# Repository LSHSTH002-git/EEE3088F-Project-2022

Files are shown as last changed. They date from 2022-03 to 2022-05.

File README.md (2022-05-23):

# EEE3088F_2022: GROUP 15 LIGHT SENSOR HAT PROJECT

In this guide we will learn to use the LIGHT SENSOR HAT that is used to detect environmental changes and then set off an alarm to alert the onwner about the changes.

This Sensor is primarily designed for farmers that want to monitor their live stock and prevent thieves from stealing them.



# What you will need
1. You will need an STM32f0discovery board

2. Li-Ion battery

3. jumpers

4.  Laptop

5. Micro usb type B male connector

6. STM32CubeIDE

7. Mini USB type A cable

8. The HAT code

9. The HAT pcb Board

# Setting up the System

Insert the Li-ion battery to the battery holder
connect the STM32f0discovery board to your laptop using the Mini USB type A cable
connect the light sensor HAT to your Laptop using Micro usb type B male connector and you should see two LED's light up
run the HAT code on your pc using STM32CubeIDE 
if you cover up the Light sensor HAT, the Blue LED on the STM32f0discovery board should blink

if you stop covering the Light sensor HAT the blue LED should stop blinking.


# License
[Creative Commons Attribution 4.0 International license](https://choosealicense.com/licenses/cc-by-4.0/)

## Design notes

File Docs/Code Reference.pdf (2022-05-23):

Code Reference

STM32F0 LSPCB1x

### Code Description of the STM32F0 LSPCB1x PCB

Introduction

The STM32F0 LSPCB1x pcb integrates with the stm32 microcontroller to perfom the necessary operations using the data retrieved from the sensor in the PCB. In this code reference document the programming language c is used, however the PCB isn’t only limited to c, c++ can also be used. Following are the fucntions used in the program, with details on how each plays into the whole fundumental program.

System Clock Configuration:

void SystemClock_Config(void);

This function initializes the Reset and Clock Control(RCC) registers of the STM32 microcontroller. The function initializes the RCC oscillators in accordance with the user specified parameters. Shown below is code snippet, showing the latter.

void SystemClock_Config(void)

{…

RCC_OscInitTypeDef RCC_OscInitStruct = {0};

RCC_OscInitStruct.OscillatorType = RCC_OSCILLATORTYPE_HSI;

…}

The function also goes on to handle initialization of the CPU, AHB and APB buses’ clocks, to which a user may modify to work best for their application.

GPIO Pins Configuration:

static void MX_GPIO_Init(void);

This function initialized the STM32 GPIO pins, to which the user may add on other pins should there be a need of some GPIO pins. The code snippet below shows how to initialize and use a GPIO pin by toggling the STM32 blue LED, but before that RCC clocks have to be enabled for the appropriate GPIOs.

static void MX_GPIO_Init(void)

{…

//enabling a clock

__HAL_RCC_GPIOC_CLK_ENABLE();

HAL_GPIO_WritePin(GPIOC, GPIO_PIN_8, GPIO_PIN_RESET

…}

Code Reference

USART2 Initialization:

static void MX_USART2_UART_Init(void);

This function handles the initialization of the USB to serial converter. A FT232RL 3.3V / 5.5V FTDI USB is integrated with the PCB for this purpose. The function sets multiple parameters for the communication link, from Baud rate to Word Length and other parameters involved. Below is code snippet showing how some of the parameters are set in the function:

static void MX_USART2_UART_Init(void)

{…

huart2.Instance = USART2;

huart2.Init.BaudRate = 9600;

huart2.Init.WordLength = UART_WORDLENGTH_8B;

…}

I2C1 Initialization:

static void MX_I2C1_Init(void);

The PCB uses the I2C communication protocol, where data is transmitted bit by bit along the SDA wire on a shared clock signal. This function initializes the I2C protocol by setting the appropriate parameters demonstrated below.

static void MX_I2C1_Init(void)

{…

hi2c1.Instance = I2C1;

hi2c1.Init.Timing = 0x2000090E;

hi2c1.Init.OwnAddress1 = 0;

…}

Code Reference
Error Detection and Handler

void Error_Handler(void);

This function is the failsafe of the program for the anticipated errors that might occur, it is the function that executes when an error is detected in the program.

void Error_Handler(void)

{…

//user may add code here.

__disable_irq();

…}

This function can be called under multiple functions if an error is detected, below is a demonstration where the function is called to perform the user desired instruction when an error is detected under USART2 initialization

static void MX_USART2_UART_Init(void)

{…

if (HAL_UART_Init(&huart2) != HAL_OK)

{

Error_Handler();

}

…}

The Main Function

int main(void);

The main function in the main.c file is the execution function of all the used functions and files for the program. From the initializations of the other functions, to the data processing where data is retrieved from the sensor, written to the EEPROM and sent to the program via the USART serial com.

All the initializing functions are called in main before any other processing is done so that all the necessary GPIOs and clocks are set. The user may extend under the main function to add other functions they may wish to add. The main function is created as follows:

int main(void)

{

//All the initializing functions are called

SystemClock_Config();

MX_GPIO_Init(void);

Code Reference

Data processing between the computer, EEPROM and the PCB sensors.

//And the user may add their own code below.

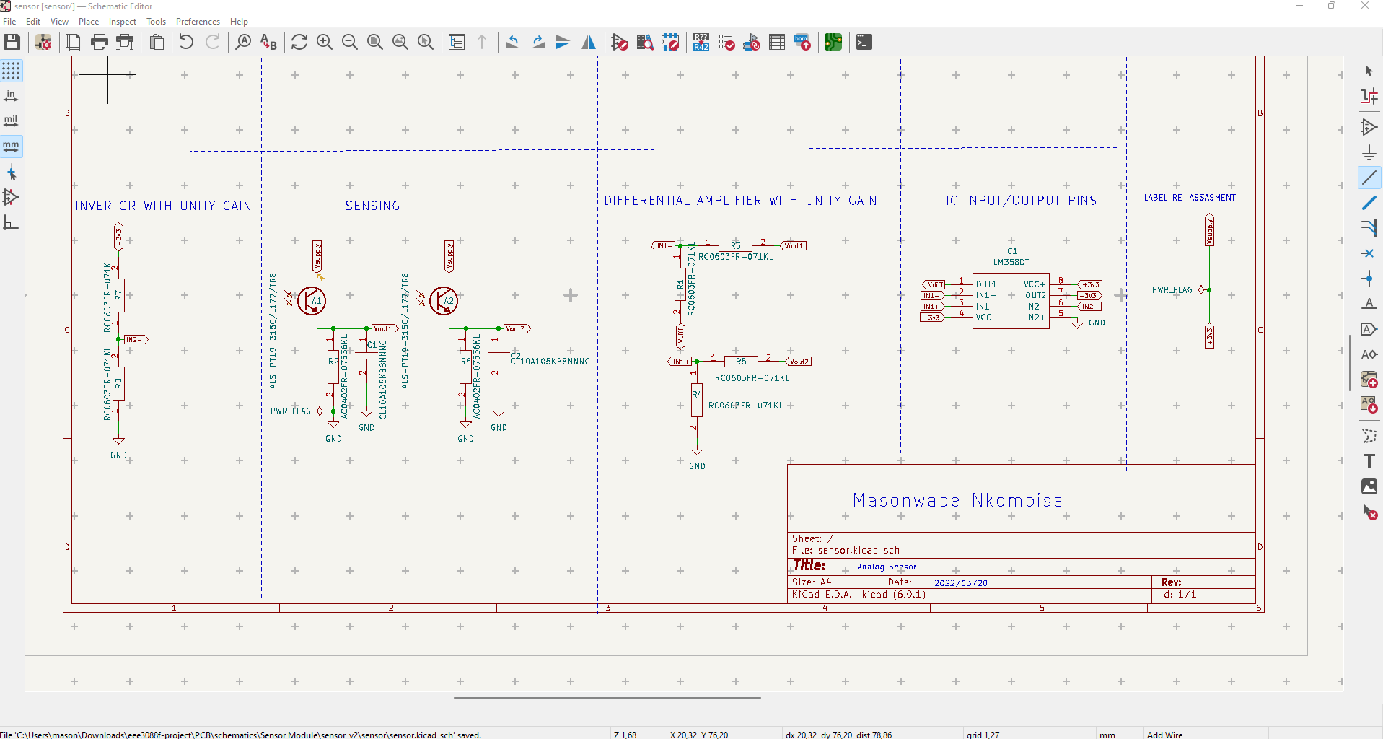
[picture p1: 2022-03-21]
PCB/schematics/Sensor Module/sensor/Sensor Sub System.png

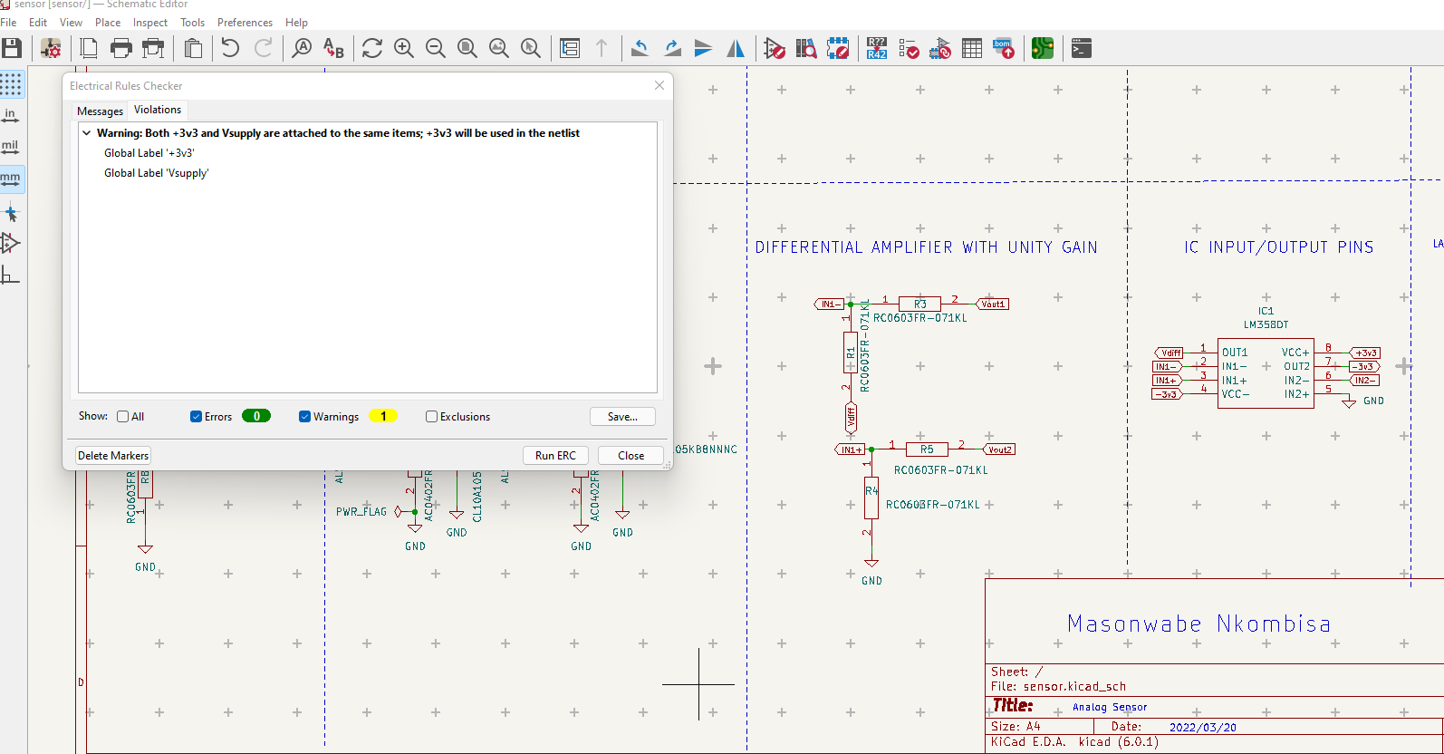
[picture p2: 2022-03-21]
PCB/schematics/Sensor Module/sensor/Sensor ERC.png

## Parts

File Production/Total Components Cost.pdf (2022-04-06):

# Total Components Cost

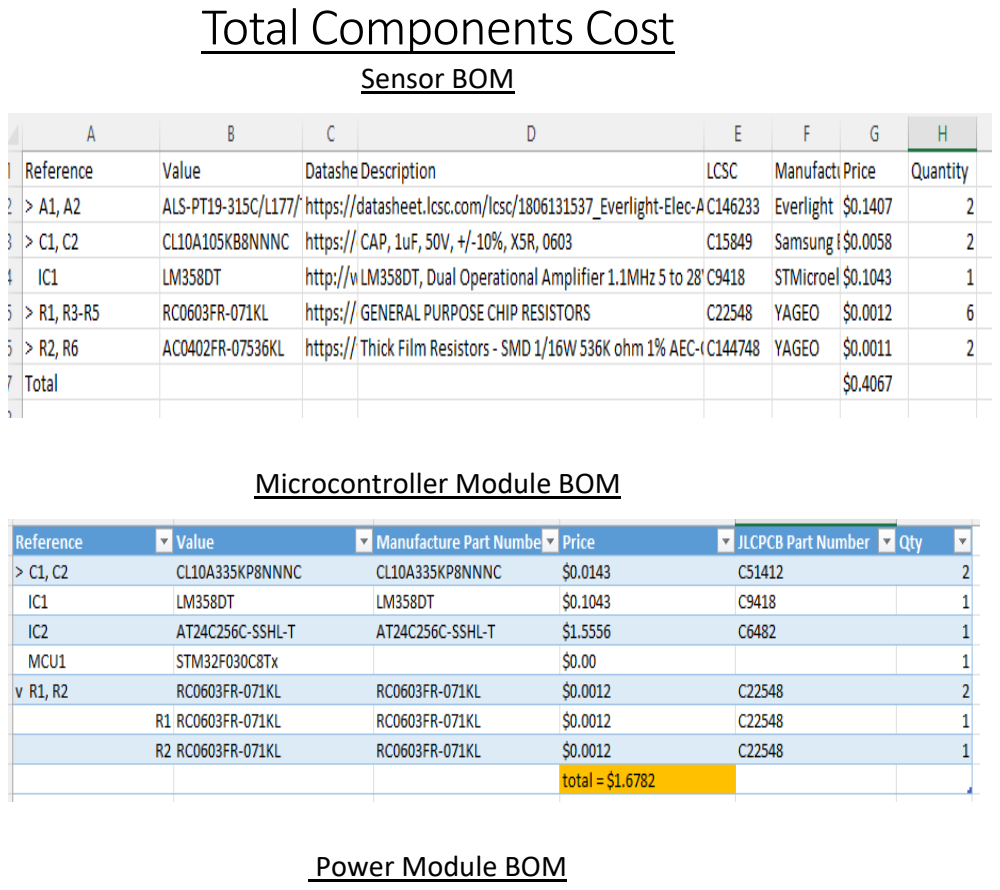
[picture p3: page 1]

Sensor BOM

Microcontroller Module BOM

Power Module BOM

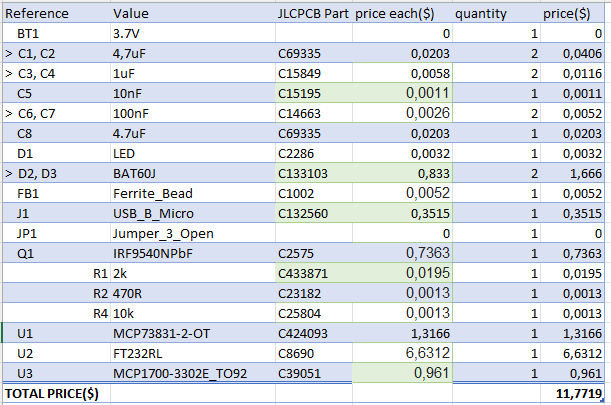
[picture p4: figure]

Total Cost of Components: $13.8568

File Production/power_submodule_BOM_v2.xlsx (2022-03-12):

Reference | Quantity | Value | JLCPCB Part | price
BT1 charger | 1 |  | CN3083 | 0.0007
BT1 | 1 | 3.7V |  | 0
C1 C2 | 2 | 4,7uF | C8032 | 0,004
C3 C4 | 2 | 1uF | C15849 | 0.0058
C5 | 1 | 10nF | C1710 | 0.0064
C6 C7 | 2 | 100nF | C14663 | 0.0026
C8 | 1 | 4.7uF | C1538 | 0.0011
D1 | 1 | LED | C264544 | 0,1584
D2 | 1 | BAT60J | C2476 | 0.108
D3 | 1 | BAT60J | C2476 | 0.108
J1 | 1 | USB_B_Micro | C132563 | 0,2511
Q1 | 1 | IRF9540NPbF | C2575 | 0.7363
R1 | 1 | 2k | C25731 | 0.0073
R2 | 1 | 470R | C425292 | 0.0059
R3 | 1 | 220R | C433520 | 0,008
R4 | 1 | 10k | C29718 | 0.0071
U1 | 1 | MCP73831-2-OT | C424093 | 1,5435
U2 | 1 | FT232RL | C8690 | 6.6312
U3 | 1 | MCP1700-3302E_TO92 | C39051 | 0.961

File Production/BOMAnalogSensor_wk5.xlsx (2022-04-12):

Reference | Value | Datasheet | Description | LCSC | Manufacture | Price | Quantity
> A1, A2 | ALS-PT19-315C/L177/TR8 | https://datasheet.lcsc.com/lcsc/1806131537_Everlight-Elec-ALS-PT19-315C-L177-TR8_C146233.pdf |  | C146233 | Everlight | $0.1407 | 2
> C1, C2 | CL10A105KB8NNNC | https://datasheet.datasheetarchive.com/originals/distributors/Datasheets-DGA10/2411562.pdf | CAP, 1uF, 50V, +/-10%, X5R, 0603 | C15849 | Samsung Electro-Mechanics | $0.0058 | 2
IC1 | LM358DT | http://www.st.com/st-web-ui/static/active/en/resource/technical/document/datasheet/CD00000464.pdf | LM358DT, Dual Operational Amplifier 1.1MHz 5 to 28V, 8-Pin SO | C9418 | STMicroelectronics | $0.1043 | 1
> R1, R3-R5 | RC0603FR-071KL | https://datasheet.datasheetarchive.com/originals/distributors/Datasheets_SAMA/902f9e387b938f871d31120f5fc1d65e.pdf | GENERAL PURPOSE CHIP RESISTORS | C22548 | YAGEO | $0.0012 | 6
> R2, R6 | AC0402FR-07536KL | https://www.yageo.com/upload/media/product/productsearch/datasheet/rchip/PYu-AC_51_RoHS_L_8.pdf | Thick Film Resistors - SMD 1/16W 536K ohm 1% AEC-Q200 | C144748 | YAGEO | $0.0011 | 2
Total |  |  |  |  |  | $0.4067

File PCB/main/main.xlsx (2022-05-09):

Comment | Designator | Footprint | LCSC
ALS-PT19-315C/L177/TR8 | A1,A2 | SamacSys_Parts:XDCR_ALS-PT19-315C_L177_TR8 | C146233
10nF | C1 | SamacSys_Parts:CAPC1608X90N | C15195
CL10A335KP8NNNC | C11,C12 | SamacSys_Parts:CAPC1608X90N | C51412
CC0603KRX7R9BB104 | C13 | SamacSys_Parts:CAPC1608X90N | C14663
CL31A106KBHNNNE | C2,C6,C7,C8 | SamacSys_Parts:CAPC3216X180N | C13585
100nF | C3,C4 | SamacSys_Parts:CAPC1608X90N | C14663
CL21C101JBANNNC | C5 | SamacSys_Parts:CAPC2012X75N | C1790
CL10A105KB8NNNC | C9,C10 | SamacSys_Parts:CAPC1608X90N | C15849
SS14 | D1,D2 | SamacSys_Parts:DIOM5227X270N | C2480
LM358DT | IC1,IC2 | SamacSys_Parts:SOIC127P600X175-8N | C9481
AT24C256C-SSHL-T | IC3 | SamacSys_Parts:SOIC127P600X175-8N | C6482
TP4056-42-ESOP8 | IC4 | SamacSys_Parts:SOIC127P600X175-9N | C16581
Conn_01x33_Female | J1,J4 | Connector_PinHeader_2.54mm:PinHeader_1x33_P2.54mm_Vertical
ICH-340-CTT | J11 | SamacSys_Parts:DIPS762W74P254L5080H338Q40N | C84681
Conn_01x33_Female | J2,J3 | Connector_PinSocket_2.54mm:PinSocket_1x33_P2.54mm_Vertical
47346-0001 | J5 | SamacSys_Parts:47346-0001 | C132560
PZ254V-11-02P | J6,J7,J9,J10 | SamacSys_Parts:HDRV2W64P0X254_1X2_508X250X873P | C492401
MTP125-1103S1 | J8,J12,J13,J14,J15 | SamacSys_Parts:HDRV3W64P0X254_1X3_762X250X885P | C358685
19-217_GHC-YR1S2_3T | LED1,LED2 | SamacSys_Parts:LEDC1608X50N | C72043
AO3401A | Q1 | SamacSys_Parts:SOT95P280X125-3N | C15127
0603WAF1201T5E | R 1 | SamacSys_Parts:RESC1608X55N | C22765
RC0603FR-071KL | R2,R4,R5,R8,R9,R10,R11,R12,R13,R14 | SamacSys_Parts:RESC1608X55N | C22548
10k | R 3 | SamacSys_Parts:RESC1608X55N | C25804
AC0402FR-07536KL | R6,R7 | SamacSys_Parts:RESC1005X37N | C144748
HT75xx-1-SOT89 | U1 | Package_TO_SOT_SMD:SOT-89-3 | C14289

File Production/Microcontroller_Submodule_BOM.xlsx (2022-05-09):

Reference | Value | Manufacture Part Number | Price | JLCPCB Part Number | Qty
> C1, C2 | CL10A335KP8NNNC | CL10A335KP8NNNC | $0.0143 | C51412 | 2
IC1 | LM358DT | LM358DT | $0.1043 | C9418 | 1
IC2 | AT24C256C-SSHL-T | AT24C256C-SSHL-T | $1.5556 | C6482 | 1
MCU1 | STM32F030C8Tx |  | $0.00 |  | 1
v R1, R2 | RC0603FR-071KL | RC0603FR-071KL | $0.0012 | C22548 | 2
R 1 | RC0603FR-071KL | RC0603FR-071KL | $0.0012 | C22548 | 1
R 2 | RC0603FR-071KL | RC0603FR-071KL | $0.0012 | C22548 | 1
 |  |  | total = $1.6782

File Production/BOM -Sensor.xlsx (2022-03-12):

Reference | Quantity | Value | Footprint | Datasheet | Populate | Price | Alt_LCSC | LCSC
C1 C2 | 2 | 1uF |  | https://datasheet.lcsc.com/lcsc/1810271109_Samsung-Electro-Mechanics-CL31B105KBHNNNE_C1848.pdf |  | 0.026$/unit |  | C1848
R1 R2 R3 R4 R5 R6 | 6 | 1k |  | https://datasheet.lcsc.com/lcsc/1811141734_FH-Guangdong-Fenghua-Advanced-Tech-RC-02W1001FT_C226166.pdf |  | 0.001$/unit |  | C226166
U1 U2 | 2 | LTR-303ALS-01 | OptoDevice:Lite-On_LTR-303ALS-01 | http://optoelectronics.liteon.com/upload/download/DS86-2013-0004/LTR-303ALS-01_DS_V1.pdf |  | 0.384$/unit |  | C364577
U3 | 1 | 4011 |  | https://datasheet.lcsc.com/lcsc/1809050910_Texas-Instruments-CD4011BM96_C48466.pdf |  |  |  | C48466

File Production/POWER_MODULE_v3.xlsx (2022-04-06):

Column1 | Column2 | Column3 | Column4 | Column5 | Column6
Reference | Value | JLCPCB Part | price each($) | quantity | price($)
BT1 | 3.7V |  | 0 | 1 | 0
> C1, C2 | 4,7uF | C69335 | 0.0203 | 2 | 0.0406
> C3, C4 | 1uF | C15849 | 0.0058 | 2 | 0.0116
C5 | 10nF | C15195 | 0.0011 | 1 | 0.0011
> C6, C7 | 100nF | C14663 | 0.0026 | 2 | 0.0052
C8 | 4.7uF | C69335 | 0.0203 | 1 | 0.0203
D1 | LED | C2286 | 0.0032 | 1 | 0.0032
> D2, D3 | BAT60J | C133103 | 0.833 | 2 | 1.666
FB1 | Ferrite_Bead | C1002 | 0.0052 | 1 | 0.0052
J1 | USB_B_Micro | C132560 | 0.3515 | 1 | 0.3515
JP1 | Jumper_3_Open |  | 0 | 1 | 0
Q1 | IRF9540NPbF | C2575 | 0.7363 | 1 | 0.7363
R 1 | 2k | C433871 | 0.0195 | 1 | 0.0195
R 2 | 470R | C23182 | 0.0013 | 1 | 0.0013
R 4 | 10k | C25804 | 0.0013 | 1 | 0.0013
U1 | MCP73831-2-OT | C424093 | 1.3166 | 1 | 1.3166
U2 | FT232RL | C8690 | 6.6312 | 1 | 6.6312
U3 | MCP1700-3302E_TO92 | C39051 | 0.961 | 1 | 0.961
TOTAL PRICE($) |  |  |  |  | 11.7719

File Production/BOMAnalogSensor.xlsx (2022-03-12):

Reference | Quantity | Value | Footprint | Datasheet | LCSC | Price
C1 | 1 | 1uF |  | https://datasheet.lcsc.com/lcsc/1810271109_Samsung-Electro-Mechanics-CL31B105KBHNNNE_C1848.pdf | C1848 | 0.026$/unit
R1 R2 R3 | 3 | 1k |  | https://datasheet.lcsc.com/lcsc/1811141734_FH-Guangdong-Fenghua-Advanced-Tech-RC-02W1001FT_C226166.pdf | C226166 | 0.001$/unit
U1 | 1 | LTR-303ALS-01 | OptoDevice:Lite-On_LTR-303ALS-01 | http://optoelectronics.liteon.com/upload/download/DS86-2013-0004/LTR-303ALS-01_DS_V1.pdf | C364577 | 0.384$/unit

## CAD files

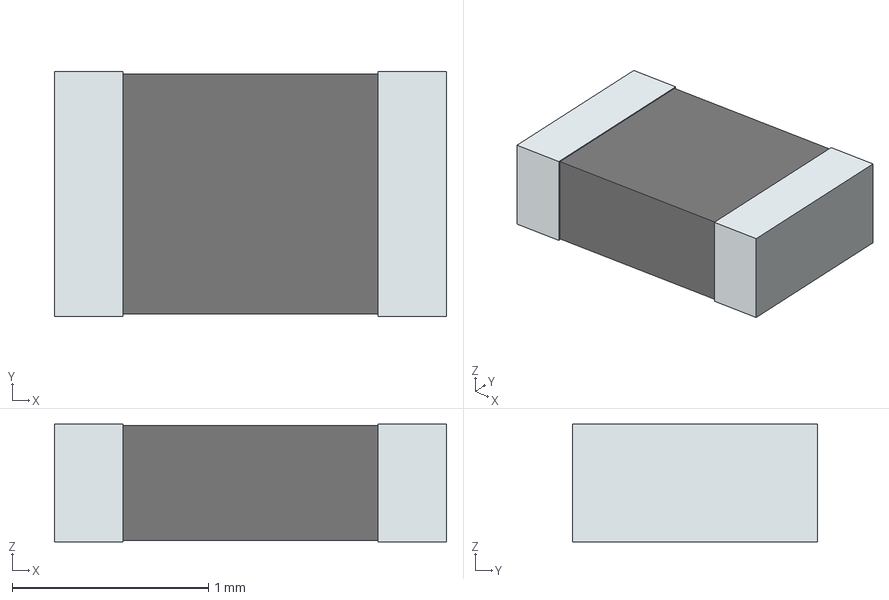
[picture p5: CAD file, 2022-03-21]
PCB/symbols and footprints/microcontroller_files/RC0805FR-07470RL.stp
2.00 x 1.25 x 0.6 mm
term1
term2

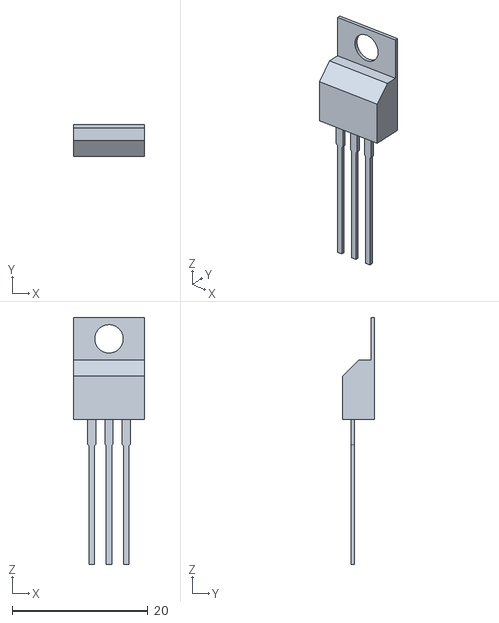
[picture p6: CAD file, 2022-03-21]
PCB/symbols and footprints/searchenginelibrary/IRF9540NPBF.stl
10.4 x 4.69 x 36.4

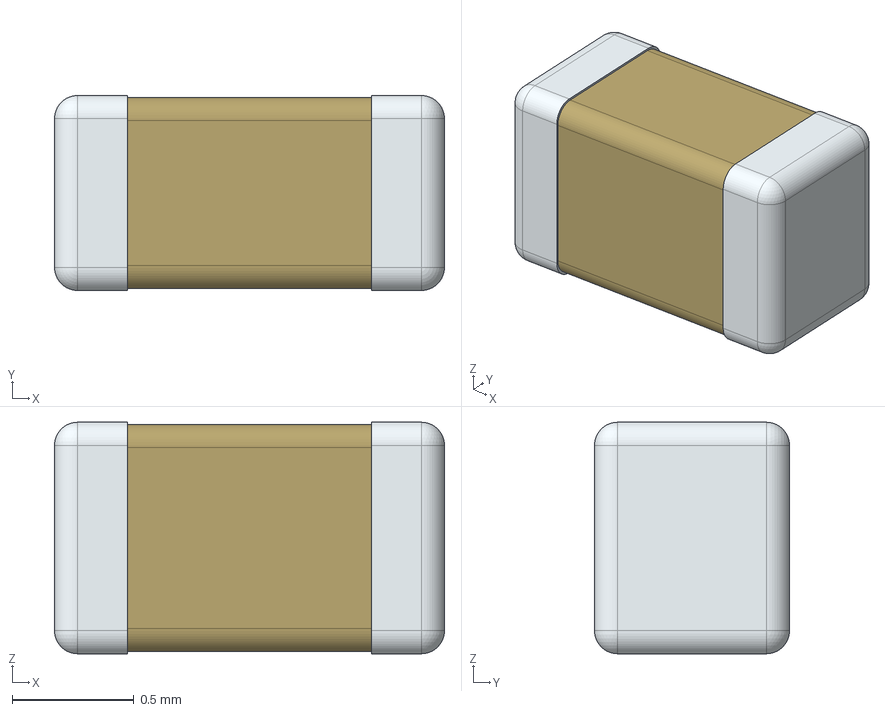
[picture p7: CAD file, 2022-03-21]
PCB/symbols and footprints/microcontroller_files/CL10A475KA8NQNC.stp
1.60 x 0.8 x 0.95 mm

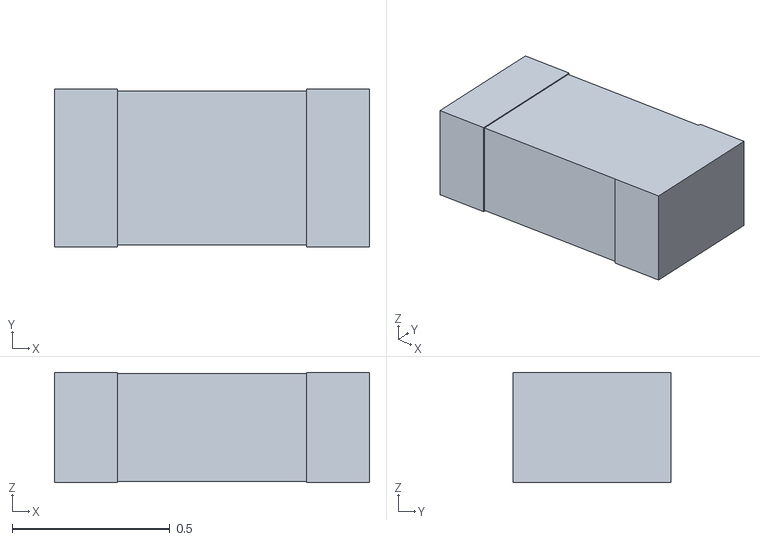
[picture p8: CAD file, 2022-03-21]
PCB/symbols and footprints/searchenginelibrary/CPF0402B2K0E1.stl
1.00 x 0.5 x 0.35

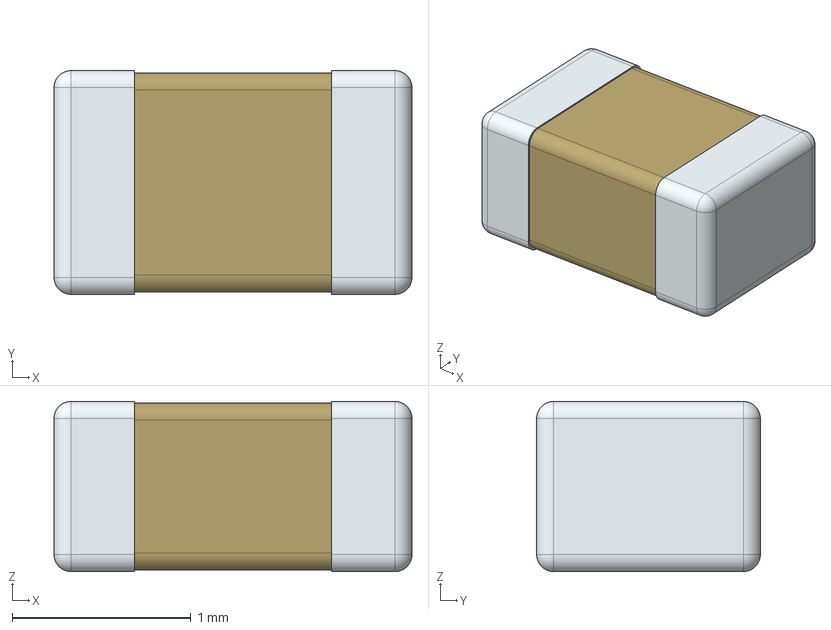
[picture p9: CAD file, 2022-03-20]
PCB/symbols and footprints/microcontroller_files/CL21B104KBCNNNC.stp
2.00 x 1.25 x 0.95 mm

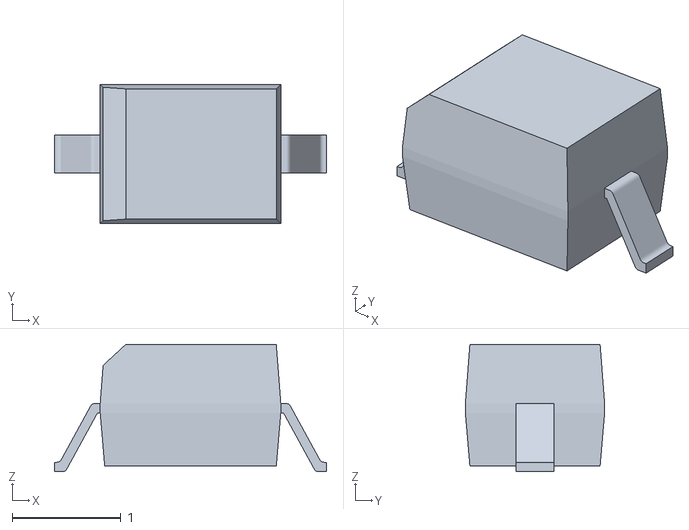
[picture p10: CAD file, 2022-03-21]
PCB/symbols and footprints/searchenginelibrary/BAT60JFILM.stl
2.50 x 1.28 x 1.17

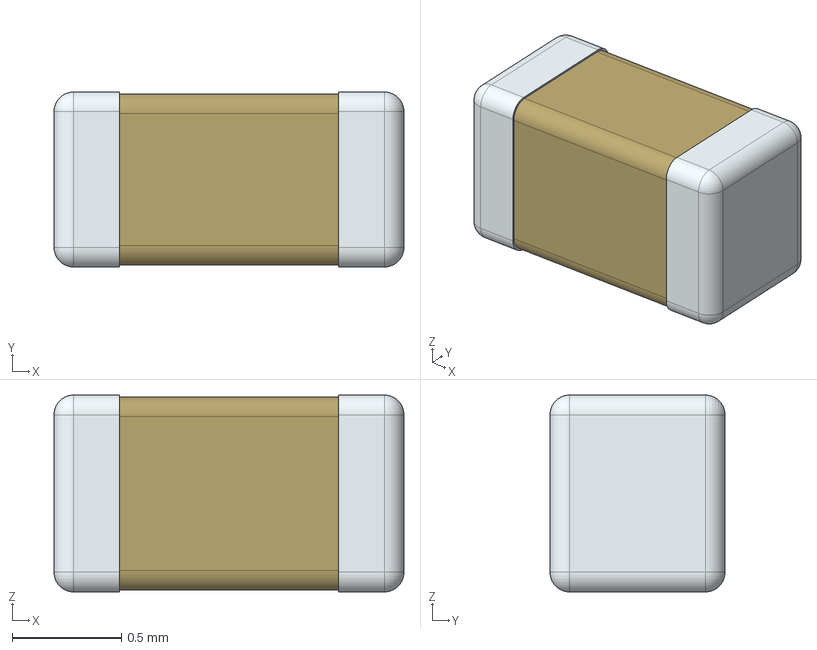
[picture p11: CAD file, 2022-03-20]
PCB/symbols and footprints/microcontroller_files/CL10A335KP8NNNC.stp
1.60 x 0.8 x 0.9 mm

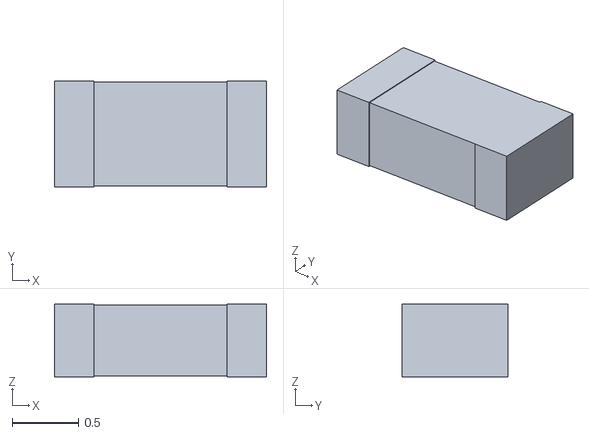
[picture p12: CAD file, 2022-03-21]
PCB/symbols and footprints/searchenginelibrary/0603WAF1002T5E.stl
1.60 x 0.8 x 0.55

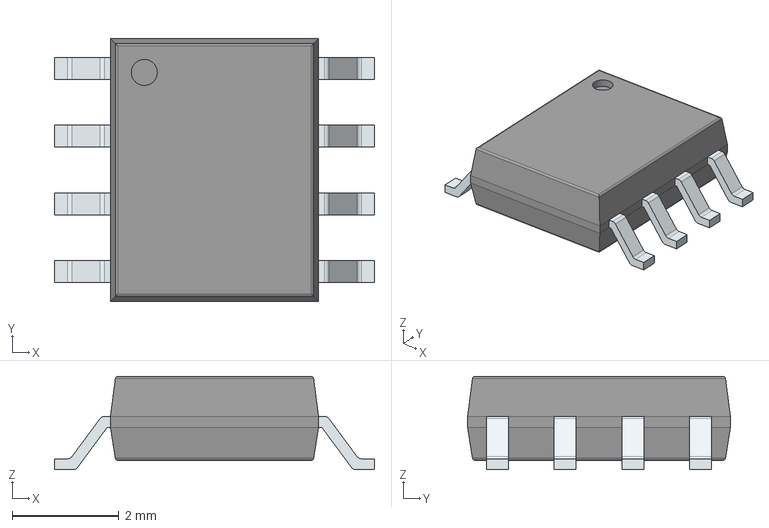
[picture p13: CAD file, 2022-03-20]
PCB/symbols and footprints/microcontroller_files/AT24C256C-SSHL-T.stp
6.00 x 4.92 x 1.75 mm
PinsArrayLR

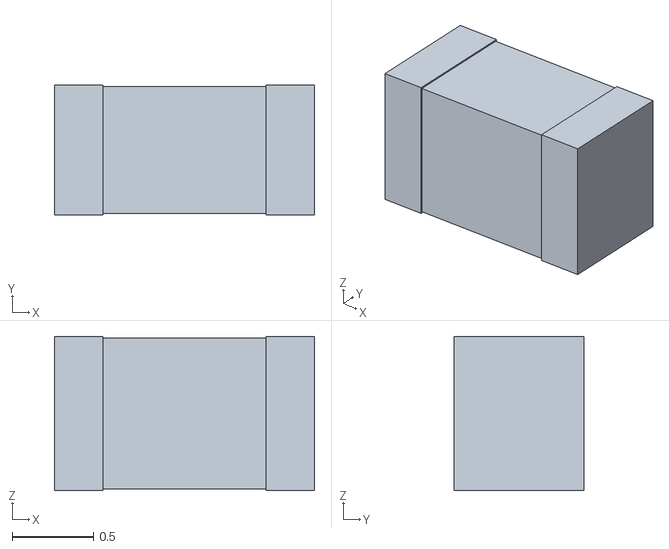
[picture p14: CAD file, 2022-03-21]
PCB/symbols and footprints/searchenginelibrary/GZ1608D601TF.stl
1.60 x 0.8 x 0.95

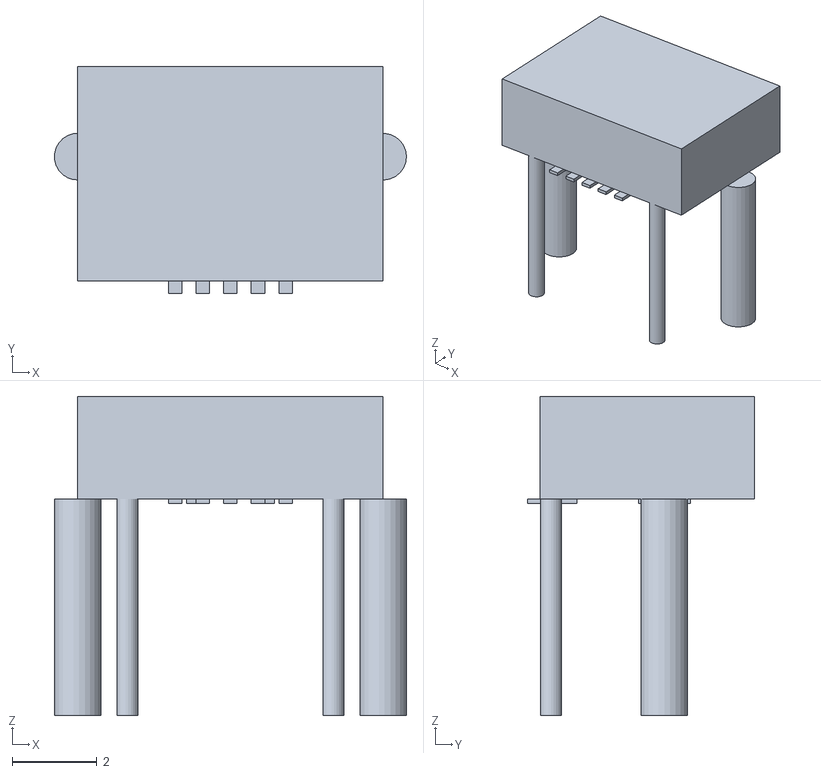
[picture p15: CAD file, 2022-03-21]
PCB/symbols and footprints/searchenginelibrary/MICROXNJ.stl
8.30 x 5.36 x 7.53

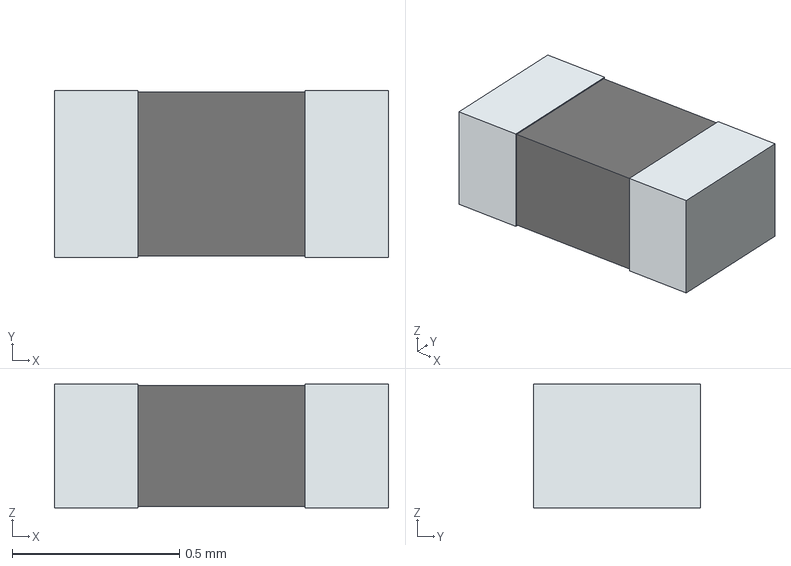
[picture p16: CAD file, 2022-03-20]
PCB/symbols and footprints/searchenginelibrary/AC0402FR-07536KL.stp
1.00 x 0.5 x 0.37 mm
term1
term2

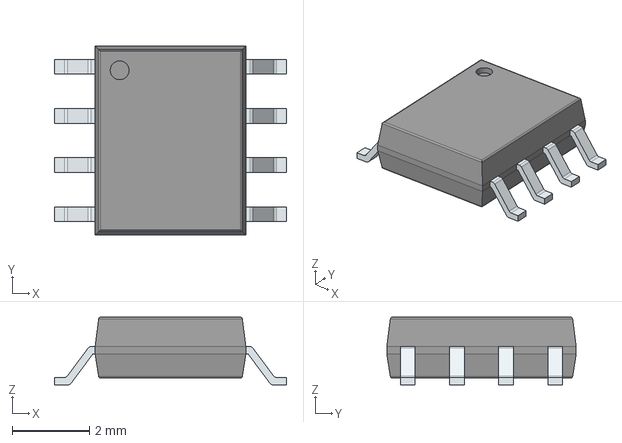
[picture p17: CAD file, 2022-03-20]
PCB/symbols and footprints/searchenginelibrary/LM358DT.stp
6.00 x 4.90 x 1.75 mm
PinsArrayLR

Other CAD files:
PCB/symbols and footprints/microcontroller_files/RC0603FR-071KL.stp
PCB/symbols and footprints/searchenginelibrary/CC0603KRX7R9BB104.stl
PCB/symbols and footprints/searchenginelibrary/CL10A475KO8NNNC.stl
PCB/symbols and footprints/searchenginelibrary/AC0402JR-0750RL.stp
PCB/symbols and footprints/microcontroller_files/AT24C256C-SSHL-T.stl
PCB/symbols and footprints/microcontroller_files/CL10A475KA8NQNC.stl
PCB/symbols and footprints/microcontroller_files/CL21B104KBCNNNC.stl
PCB/symbols and footprints/microcontroller_files/RC0603FR-071KL.stl
PCB/symbols and footprints/microcontroller_files/RC0805FR-07470RL.stl
PCB/symbols and footprints/searchenginelibrary/AC0402FR-07536KL.stl
PCB/symbols and footprints/searchenginelibrary/AC0402JR-0750RL.stl
PCB/symbols and footprints/searchenginelibrary/CL05B103KB5NNNC.stl
PCB/symbols and footprints/searchenginelibrary/CR0805-FX-5110ELF.stp
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

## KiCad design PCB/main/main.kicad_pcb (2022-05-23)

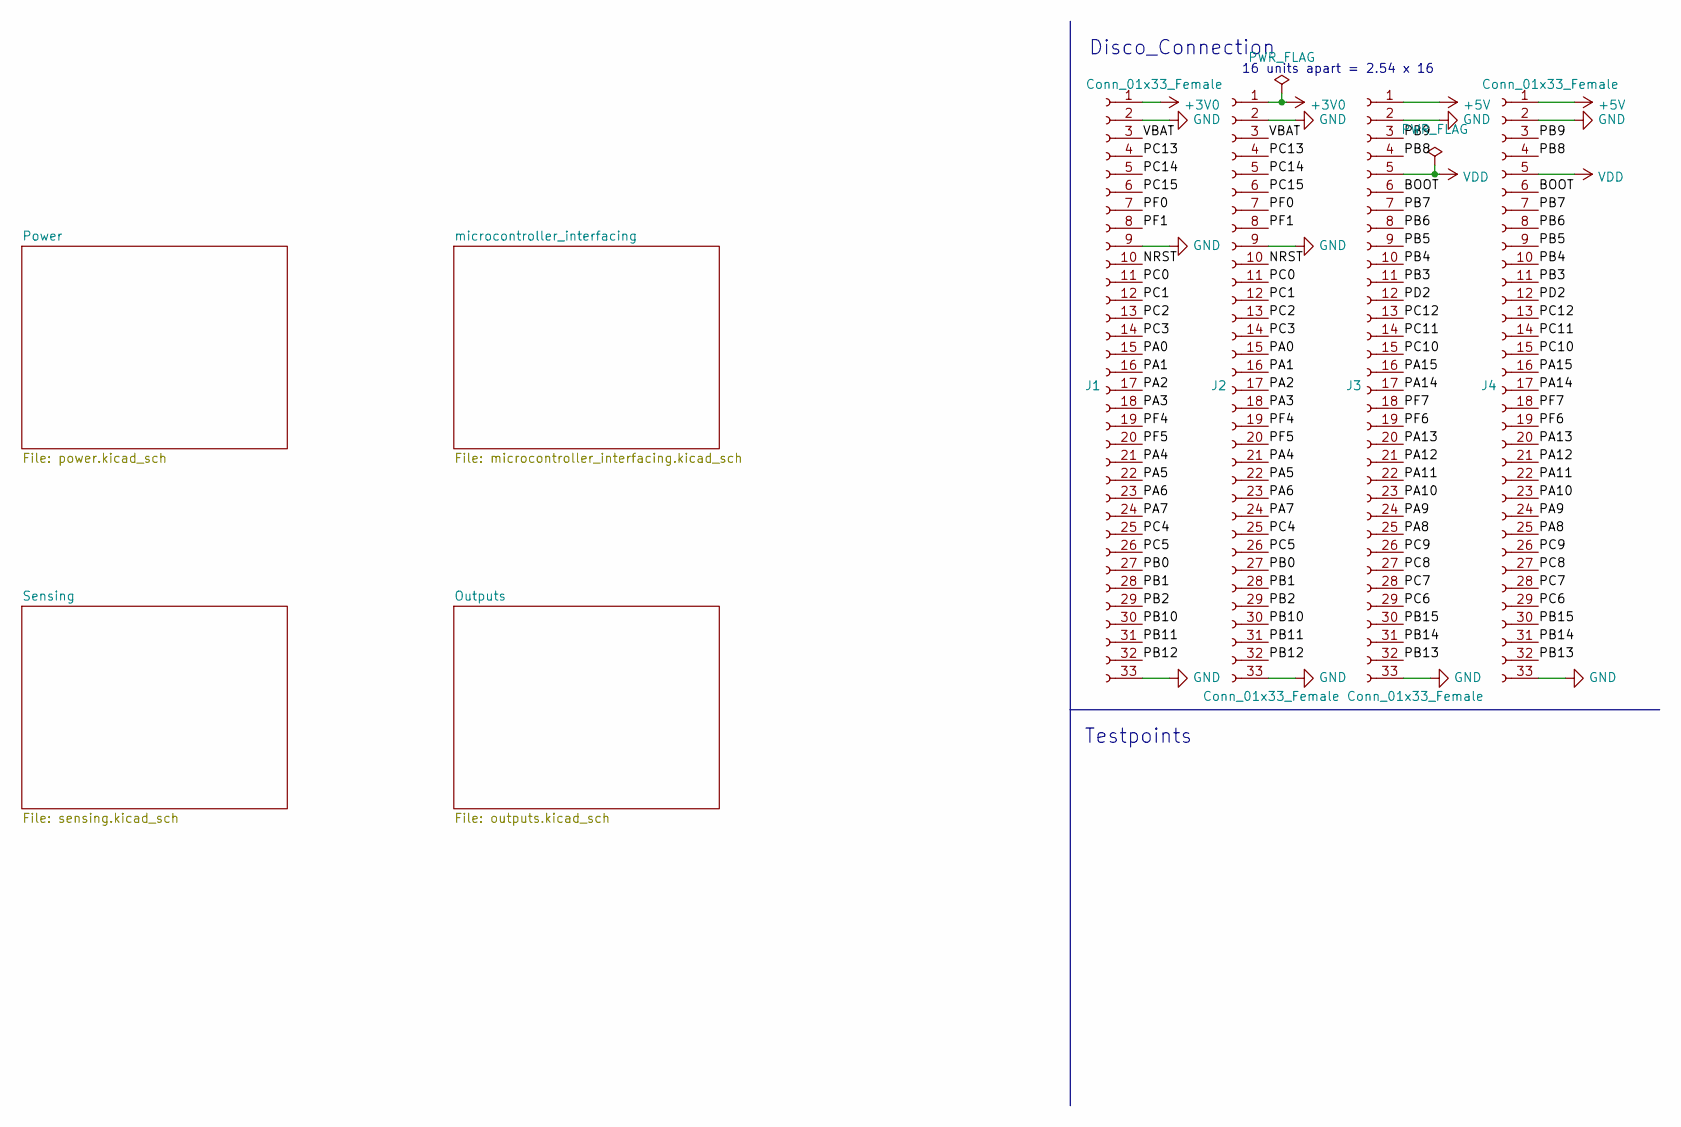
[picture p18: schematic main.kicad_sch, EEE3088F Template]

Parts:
J1, J4: Conn_01x33_Female; PinHeader_1x33_P2.54mm_Vertical
J2, J3: Conn_01x33_Female; PinSocket_1x33_P2.54mm_Vertical

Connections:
5V USB: J3.1, J4.1; also elsewhere on the board
+3V0: J1.1, J2.1
/BOOT: J3.6, J4.6
/NRST: J1.10, J2.10
/PA0: J1.15, J2.15
/PA1: J1.16, J2.16
/PA2: J1.17, J2.17
/PA3: J1.18, J2.18
/PA4: J1.21, J2.21
/PA5: J1.22, J2.22
/PA6: J1.23, J2.23
/PA7: J1.24, J2.24
/PA8: J3.25, J4.25
/PA9: J3.24, J4.24
/PA10: J3.23, J4.23
/PA11: J3.22, J4.22
/PA12: J3.21, J4.21
/PA13: J3.20, J4.20
/PA14: J3.17, J4.17
/PA15: J3.16, J4.16
/PB0: J1.27, J2.27
/PB1: J1.28, J2.28
/PB2: J1.29, J2.29
/PB3: J3.11, J4.11
/PB4: J3.10, J4.10
/PB5: J3.9, J4.9
/PB6: J3.8, J4.8
/PB7: J3.7, J4.7
/PB8: J3.4, J4.4
/PB9: J3.3, J4.3
/PB10: J1.30, J2.30
/PB11: J1.31, J2.31
/PB12: J1.32, J2.32
/PB13: J3.32, J4.32
/PB14: J3.31, J4.31
/PB15: J3.30, J4.30
/PC0: J1.11, J2.11
/PC1: J1.12, J2.12
/PC2: J1.13, J2.13
/PC3: J1.14, J2.14
/PC4: J1.25, J2.25
/PC5: J1.26, J2.26
/PC6: J3.29, J4.29
/PC7: J3.28, J4.28
/PC8: J3.27, J4.27
/PC9: J3.26, J4.26
/PC10: J3.15, J4.15
/PC11: J3.14, J4.14
/PC12: J3.13, J4.13
/PC13: J1.4, J2.4
/PC14: J1.5, J2.5
/PC15: J1.6, J2.6
/PD2: J3.12, J4.12
/PF0: J1.7, J2.7
/PF1: J1.8, J2.8
/PF4: J1.19, J2.19
/PF5: J1.20, J2.20
/PF6: J3.19, J4.19
/PF7: J3.18, J4.18
/VBAT: J1.3, J2.3
GND: J1.2, J1.9, J1.33, J2.2, J2.9, J2.33, J3.2, J3.33, J4.2, J4.33; also elsewhere on the board
VDD: J3.5, J4.5

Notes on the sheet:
16 units apart = 2.54 x 16
Disco_Connection
Testpoints

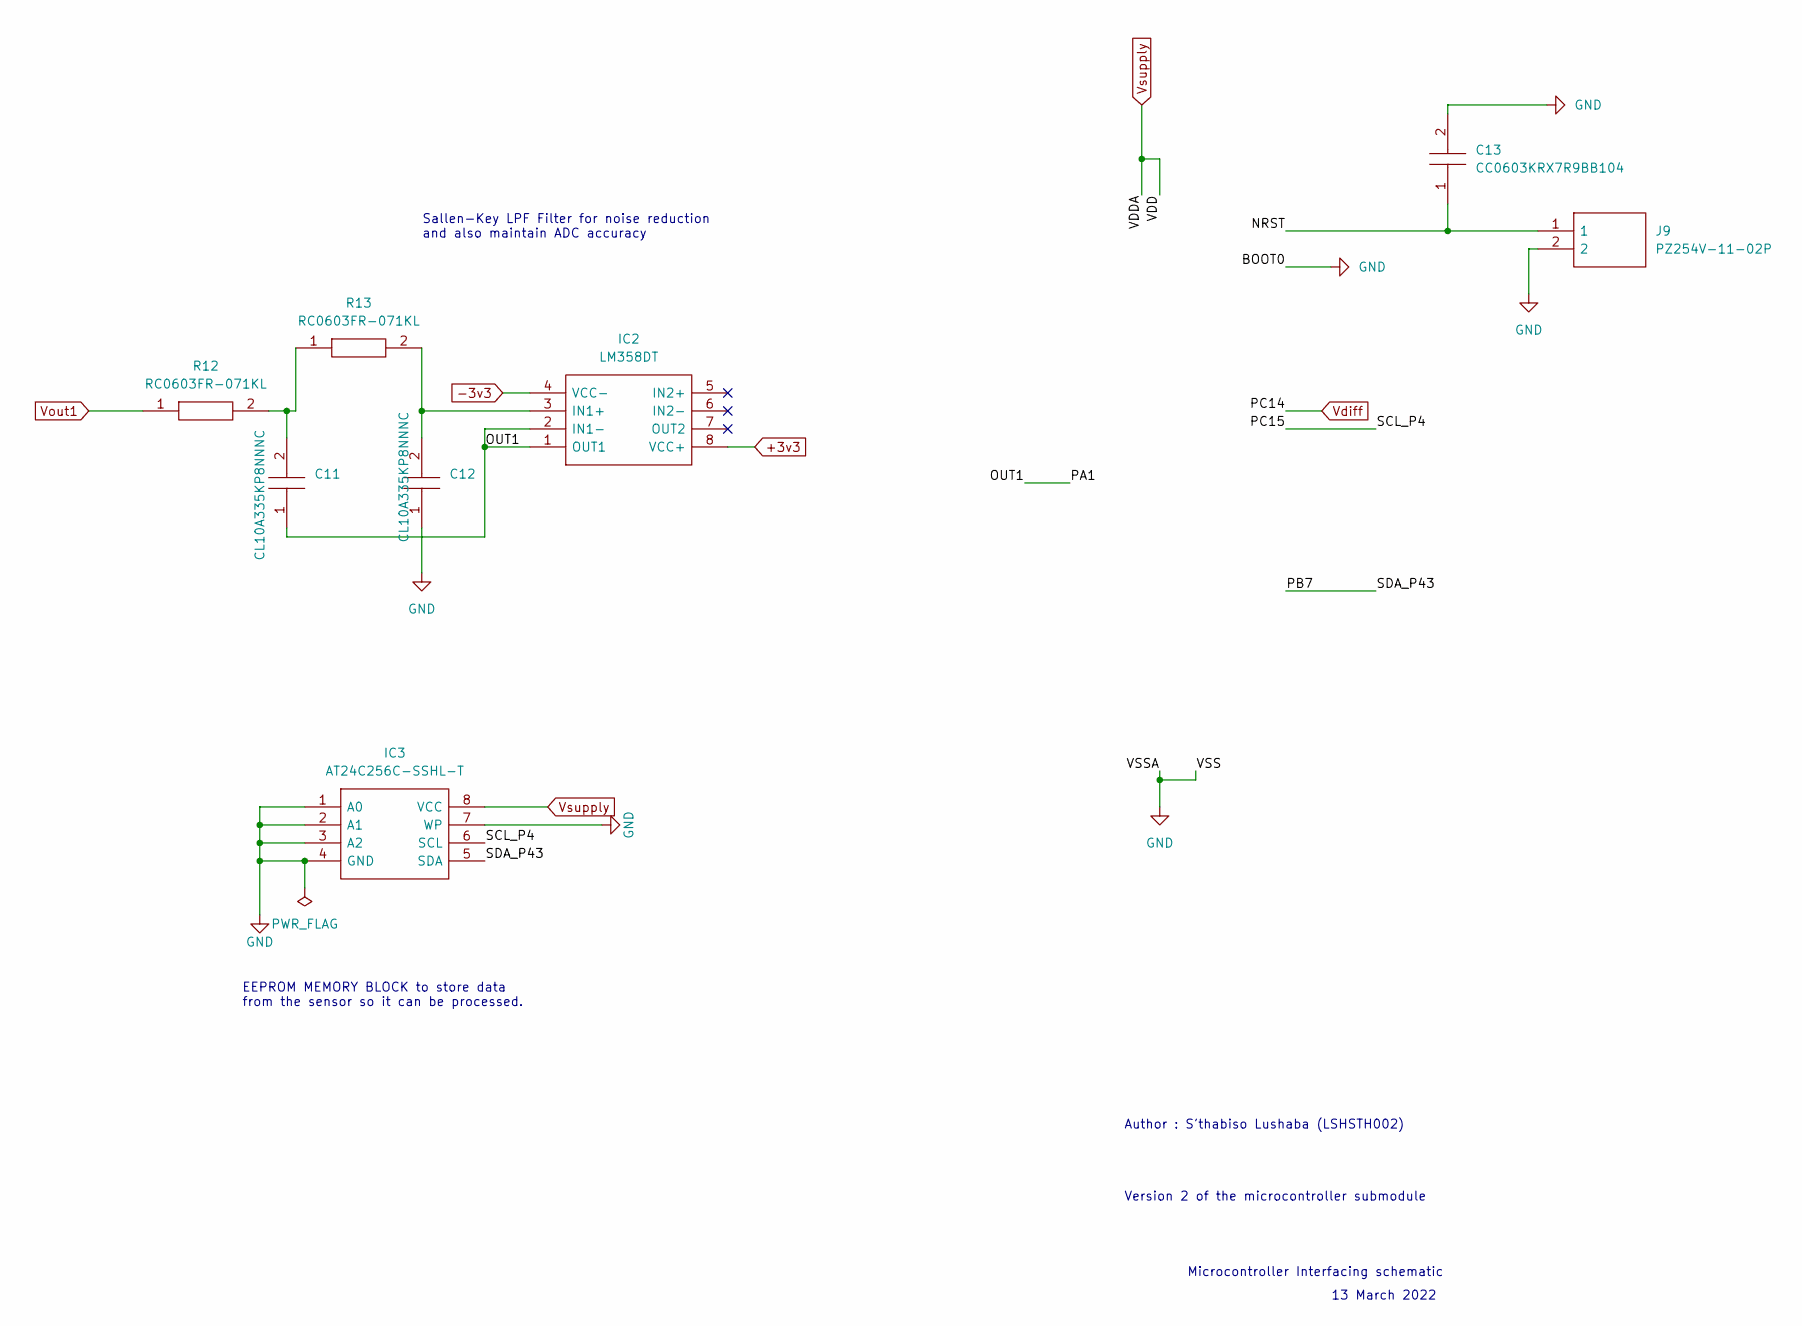
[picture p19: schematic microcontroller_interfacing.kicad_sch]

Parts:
C11, C12: CL10A335KP8NNNC; CAPC1608X90N; Manufacturer_Part_Number CL10A335KP8NNNC; Mouser Part Number N/A
C13: CC0603KRX7R9BB104; CAPC1608X90N; Manufacturer_Part_Number CC0603KRX7R9BB104; Mouser Part Number 603-CC603KRX7R9BB104
IC2: LM358DT; SOIC127P600X175-8N; Manufacturer_Part_Number LM358DT; Mouser Part Number 511-LM358DT
IC3: AT24C256C-SSHL-T; SOIC127P600X175-8N; Manufacturer_Part_Number AT24C256C-SSHL-T; Mouser Part Number 556-AT24C256C-SSHL-T
J9: PZ254V-11-02P; HDRV2W64P0X254_1X2_508X250X873P; Manufacturer_Part_Number PZ254V-11-02P; JLCPCB Part Number C492401
R12, R13: RC0603FR-071KL; RESC1608X55N; Manufacturer_Part_Number RC0603FR-071KL; Mouser Part Number 603-RC0603FR-071KL

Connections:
+3v3: IC2.8 (VCC+), IC3.8 (VCC); also elsewhere on the board
-3v3: IC2.4 (VCC-); also elsewhere on the board
/microcontroller_interfacing/NRST: C13.1, J9.1
/microcontroller_interfacing/OUT1: C11.1, IC2.1 (OUT1), IC2.2 (IN1-)
/microcontroller_interfacing/PB7: IC3.5 (SDA)
/microcontroller_interfacing/PC15: IC3.6 (SCL)
GND: C12.1, C13.2, IC3.1 (A0), IC3.2 (A1), IC3.3 (A2), IC3.4 (GND), IC3.7 (WP), J9.2; also elsewhere on the board
unnamed: C11.2, R12.2, R13.1
unnamed: C12.2, IC2.3 (IN1+), R13.2
Vout1: R12.1; also elsewhere on the board

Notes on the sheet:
Author : S'thabiso Lushaba (LSHSTH002)
Version 2 of the microcontroller submodule
Microcontroller Interfacing schematic
13 March 2022
EEPROM MEMORY BLOCK to store data from the sensor so it can be processed.
Sallen-Key LPF Filter for noise reduction and also maintain ADC accuracy

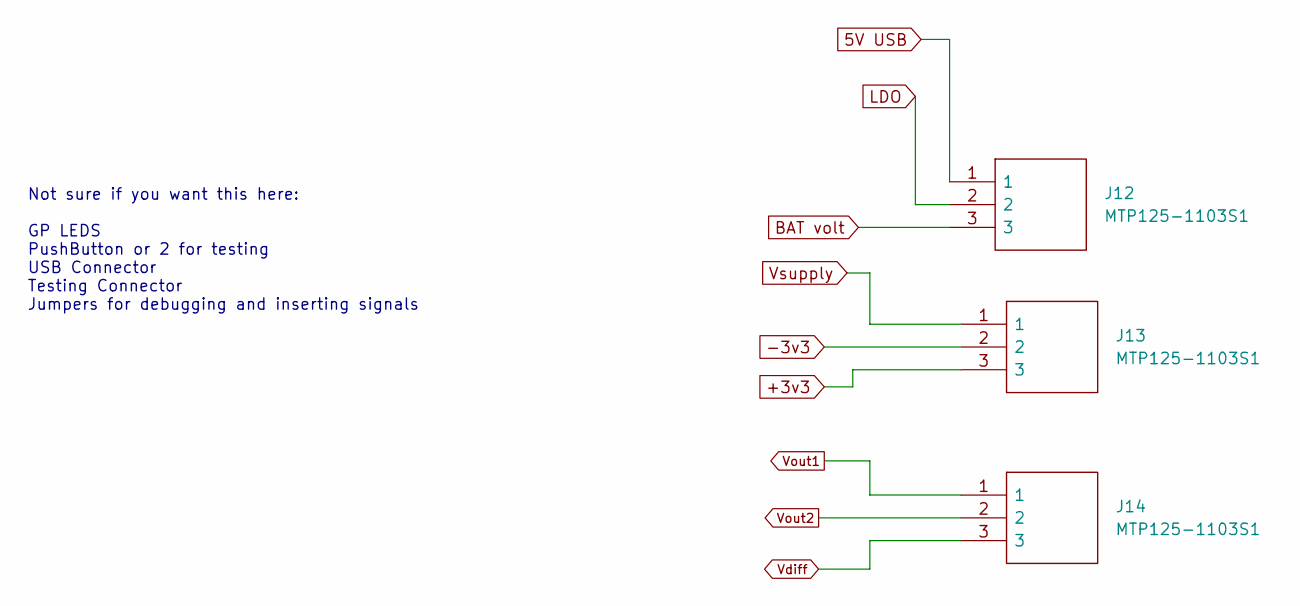
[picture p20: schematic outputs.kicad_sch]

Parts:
J12, J13, J14: MTP125-1103S1; HDRV3W64P0X254_1X3_762X250X885P; Manufacturer_Part_Number MTP125-1103S1; LCSC C358685

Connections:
5V USB: J12.1; also elsewhere on the board
+3v3: J13.1, J13.3; also elsewhere on the board
-3v3: J13.2; also elsewhere on the board
BAT volt: J12.3; also elsewhere on the board
LDO: J12.2; also elsewhere on the board
Vdiff: J14.3; also elsewhere on the board
Vout1: J14.1; also elsewhere on the board
Vout2: J14.2; also elsewhere on the board

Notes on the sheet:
Not sure if you want this here: GP LEDS PushButton or 2 for testing USB Connector Testing Connector Jumpers for debugging and inserting signals

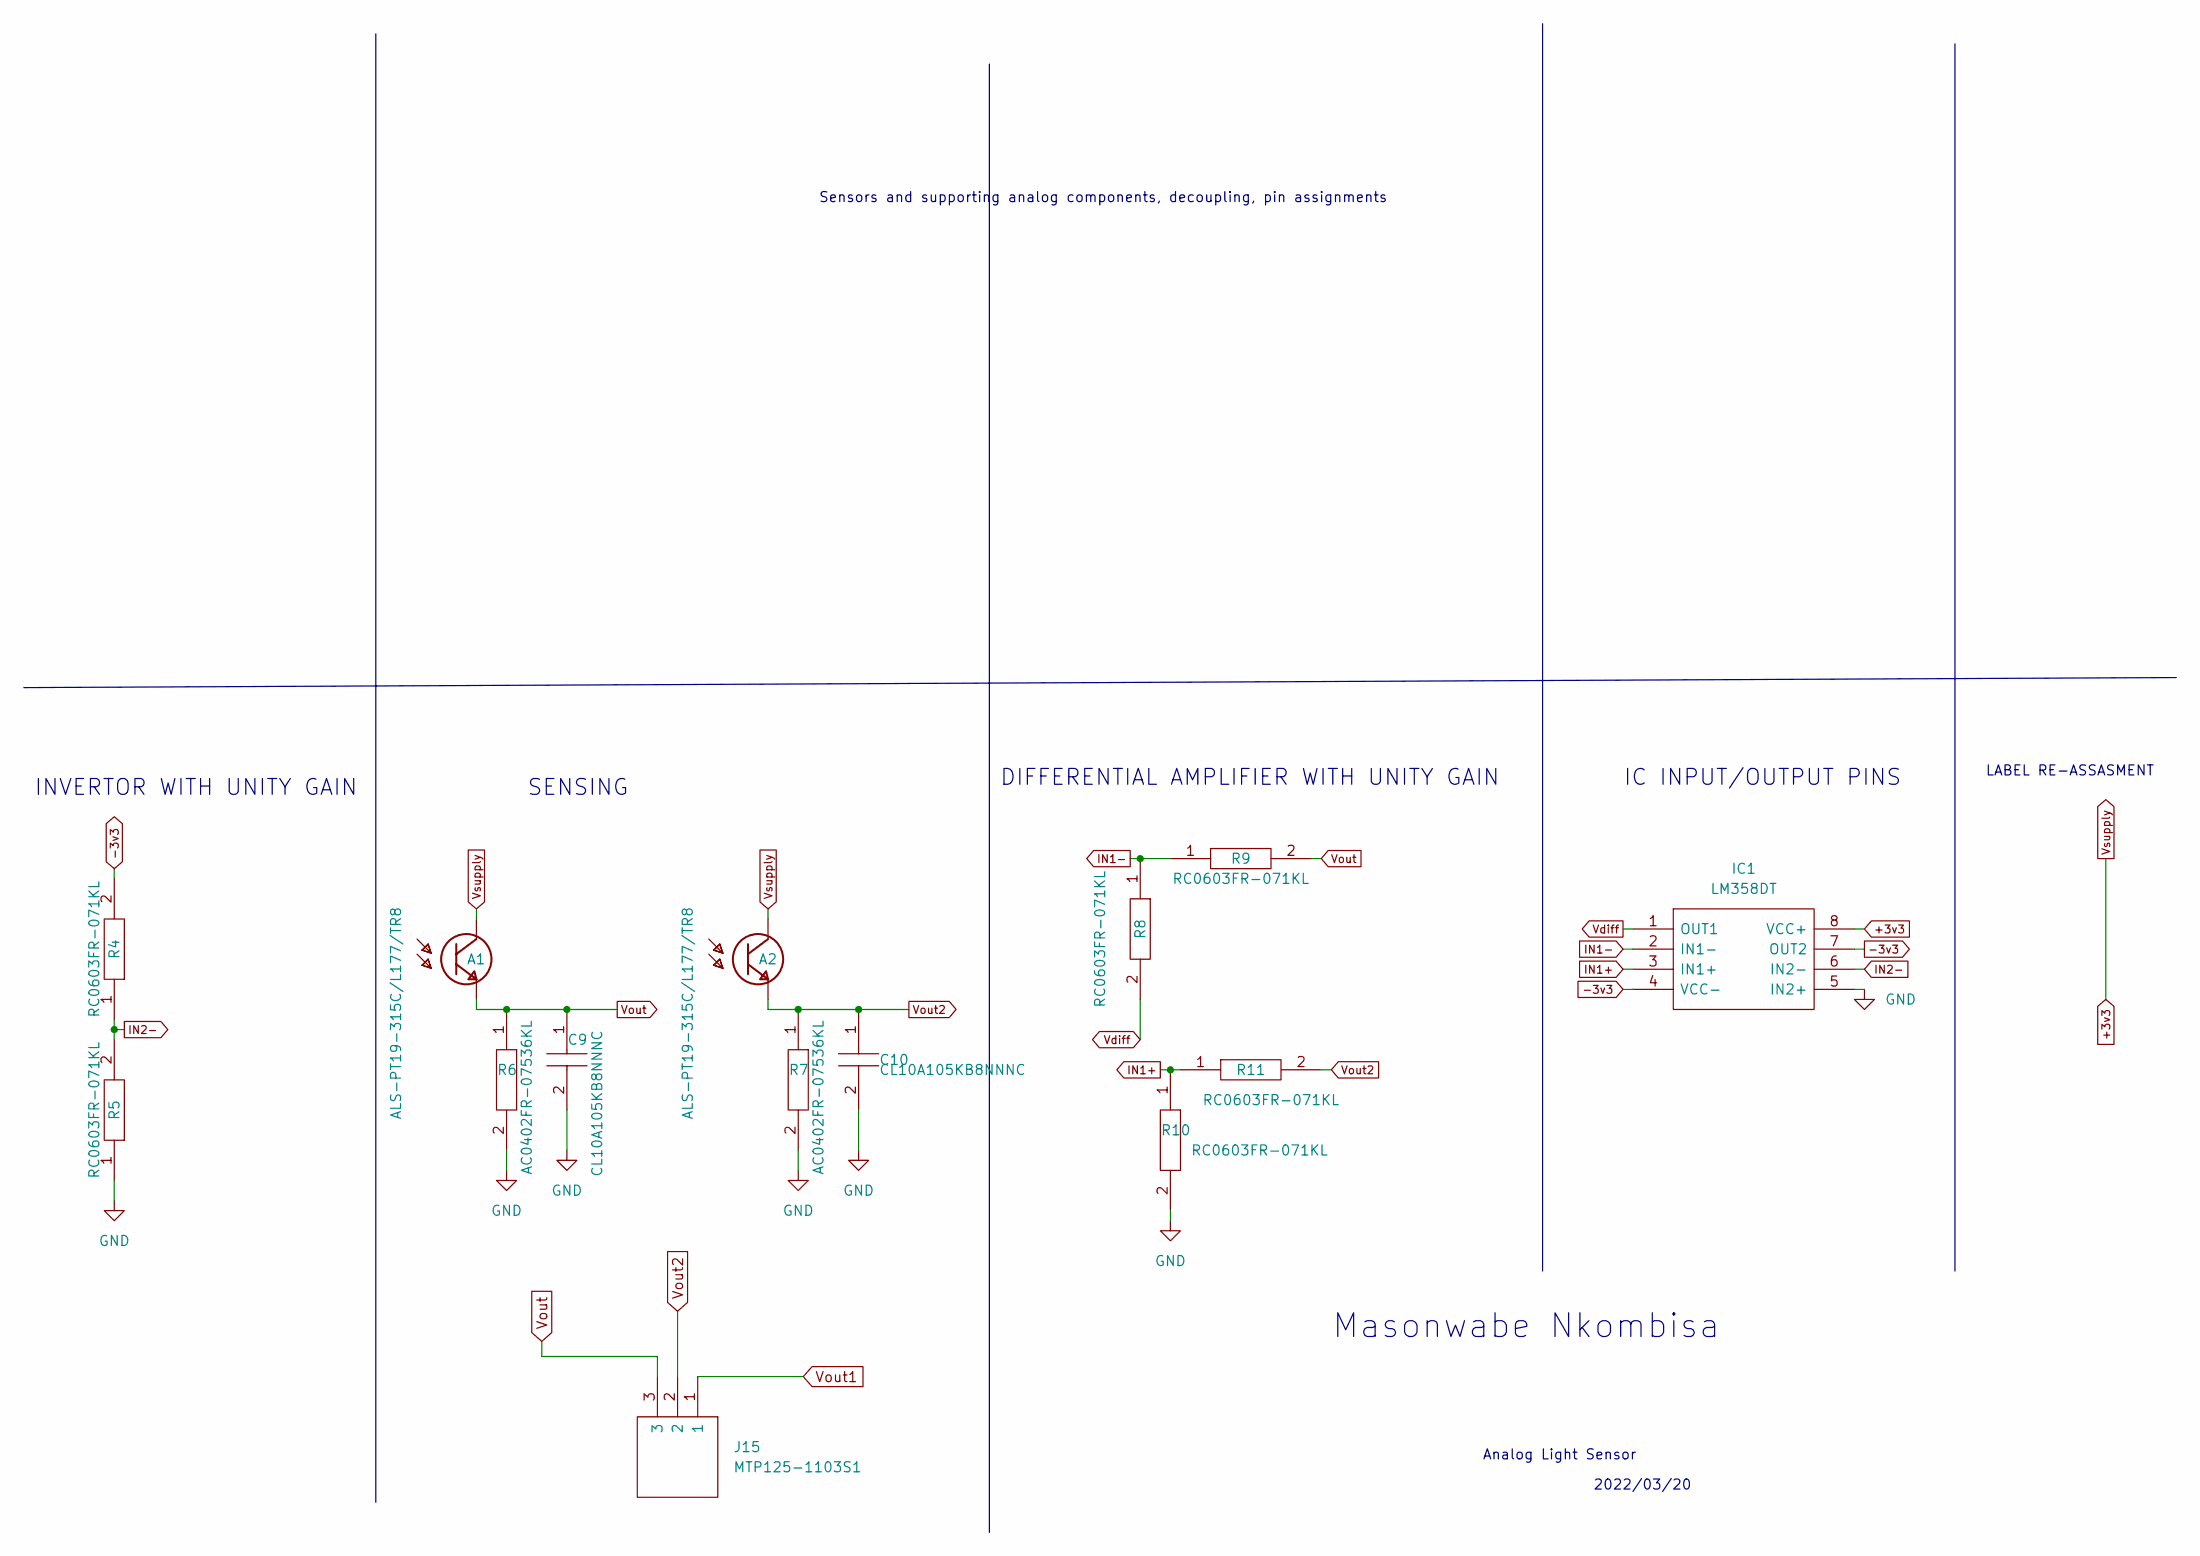
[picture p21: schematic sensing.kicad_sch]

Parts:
A1, A2: ALS-PT19-315C/L177/TR8; XDCR_ALS-PT19-315C_L177_TR8; PARTREV 5; LCSC C146233
C9, C10: CL10A105KB8NNNC; CAPC1608X90N; Manufacturer_Part_Number CL10A105KB8NNNC; Mouser Part Number 187-CL10A105KB8NNNC
IC1: LM358DT; SOIC127P600X175-8N; Manufacturer_Part_Number LM358DT; Mouser Part Number 511-LM358DT
J15: MTP125-1103S1; HDRV3W64P0X254_1X3_762X250X885P; Manufacturer_Part_Number MTP125-1103S1; LCSC C358685
R4, R5, R8, R9, R10, R11: RC0603FR-071KL; RESC1608X55N; Manufacturer_Part_Number RC0603FR-071KL; Mouser Part Number 603-RC0603FR-071KL
R6, R7: AC0402FR-07536KL; RESC1005X37N; Manufacturer_Part_Number AC0402FR-07536KL; Mouser Part Number 603-AC0402FR-07536KL

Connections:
+3v3: A1.1, A2.1, IC1.8 (VCC+); also elsewhere on the board
-3v3: IC1.4 (VCC-), IC1.7 (OUT2), R4.2; also elsewhere on the board
GND: C9.2, C10.2, IC1.5 (IN2+), R5.1, R6.2, R7.2, R10.2; also elsewhere on the board
IN1+: IC1.3 (IN1+), R10.1, R11.1
IN1-: IC1.2 (IN1-), R8.1, R9.1
IN2-: IC1.6 (IN2-), R4.1, R5.2
Vdiff: IC1.1 (OUT1), R8.2; also elsewhere on the board
Vout: A1.2, C9.1, J15.3, R6.1, R9.2
Vout1: J15.1; also elsewhere on the board
Vout2: A2.2, C10.1, J15.2, R7.1, R11.2; also elsewhere on the board

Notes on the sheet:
SENSING
LABEL RE-ASSASMENT
IC INPUT/OUTPUT PINS
Sensors and supporting analog components, decoupling, pin assignments
INVERTOR WITH UNITY GAIN
Analog Light Sensor
Masonwabe Nkombisa
DIFFERENTIAL AMPLIFIER WITH UNITY GAIN
2022/03/20

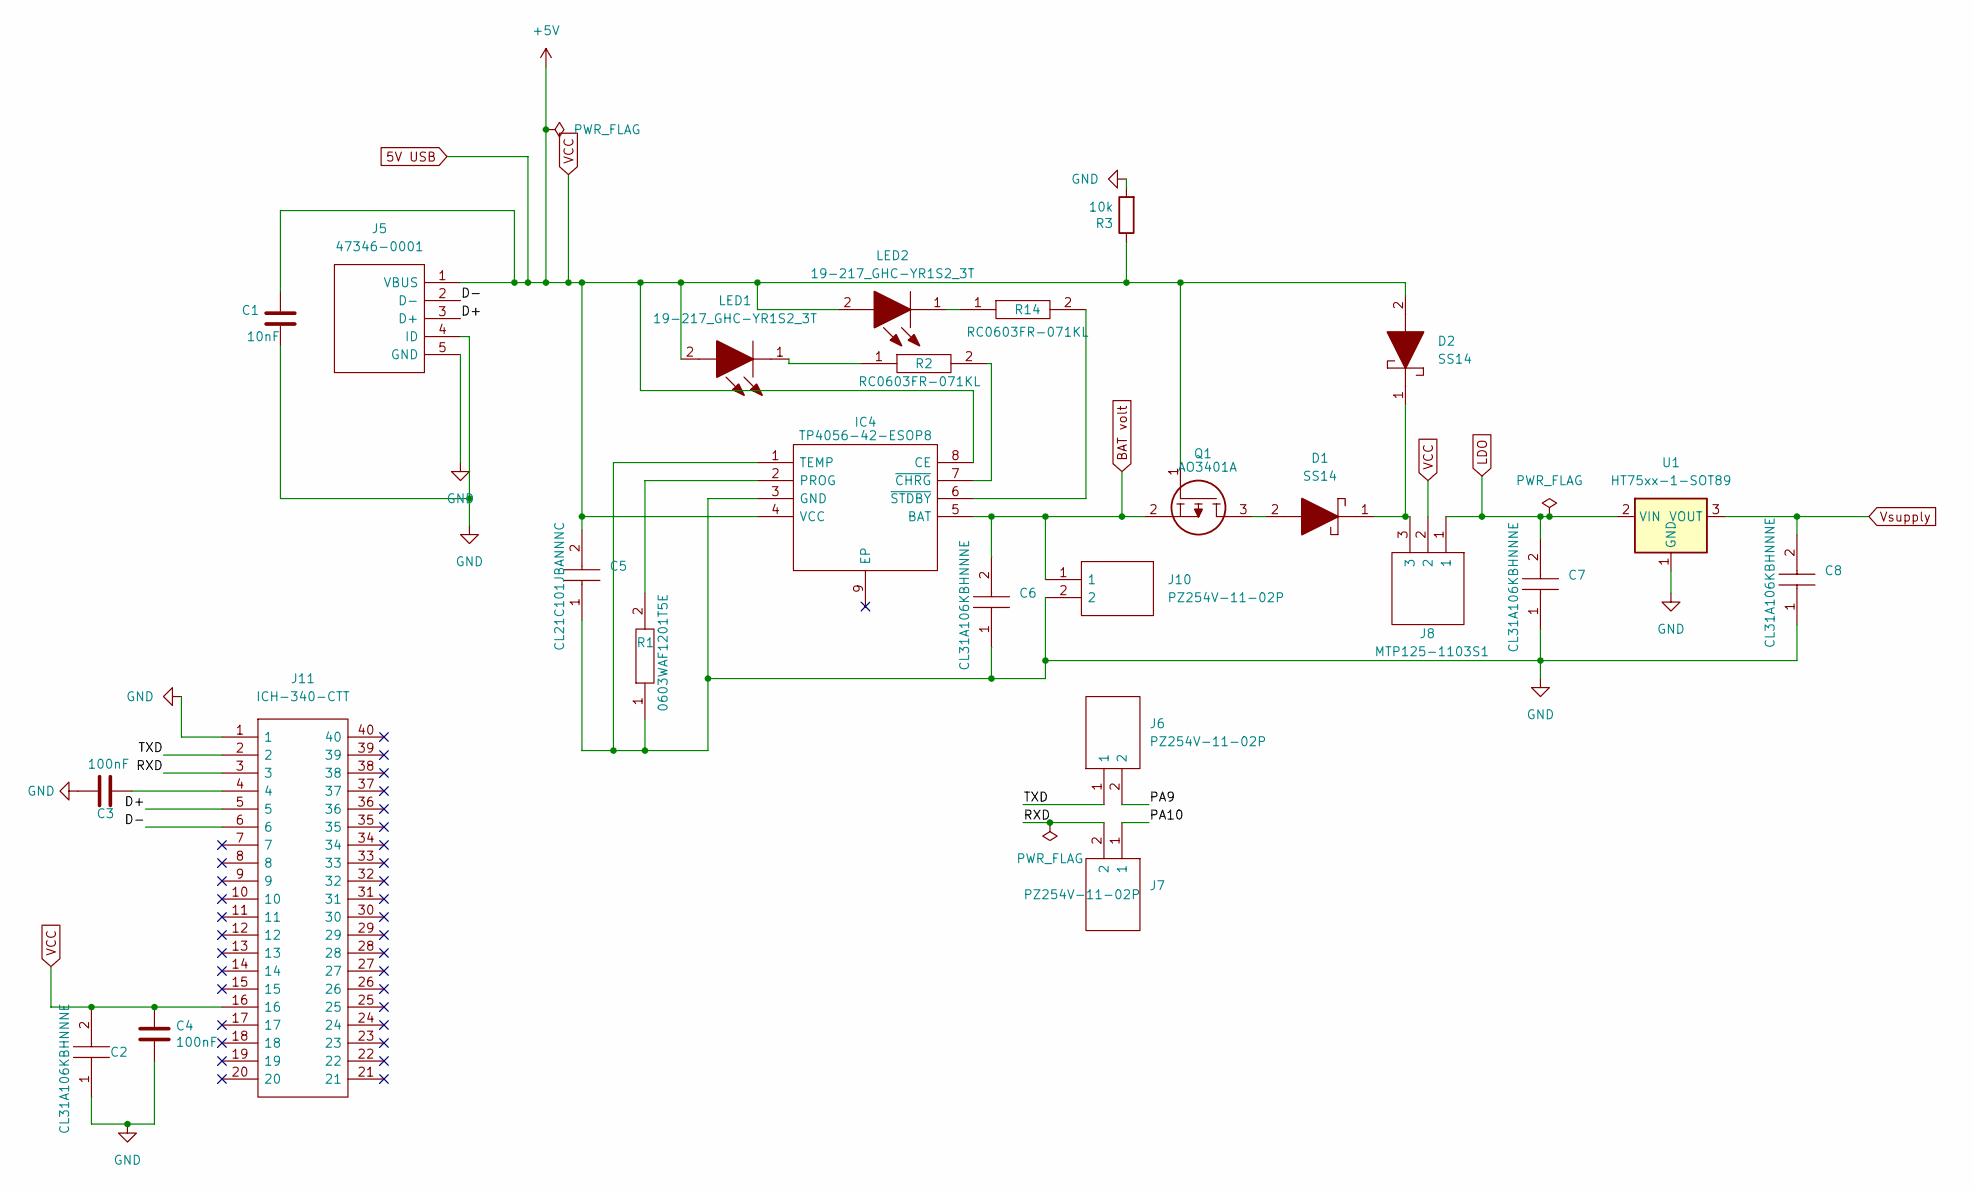
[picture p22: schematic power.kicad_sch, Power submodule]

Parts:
C1: 10nF; CAPC1608X90N; JLCPCB Part Number C15195
C2, C6, C7, C8: CL31A106KBHNNNE; CAPC3216X180N; Manufacturer_Part_Number CL31A106KBHNNNE; Mouser Part Number 187-CL31A106KBHNNNE
C3, C4: 100nF; CAPC1608X90N; JLCPCB Part Number C14663
C5: CL21C101JBANNNC; CAPC2012X75N; Manufacturer_Part_Number CL21C101JBANNNC; Mouser Part Number 187-CL21C101JBANNNC
D1, D2: SS14; DIOM5227X270N; Manufacturer_Part_Number SS14; Mouser Part Number 512-SS14
IC4: TP4056-42-ESOP8; SOIC127P600X175-9N; Manufacturer_Part_Number TP4056-42-ESOP8; LCSC C16581
J5: 47346-0001; Manufacturer_Part_Number 47346-0001; Mouser Part Number 538-47346-0001
J6, J7: PZ254V-11-02P; HDRV2W64P0X254_1X2_508X250X873P; Manufacturer_Part_Number PZ254V-11-02P; JLCPCB Part Number C492401
J8: MTP125-1103S1; HDRV3W64P0X254_1X3_762X250X885P; Manufacturer_Part_Number MTP125-1103S1; JLCPCB Part Number C358685
J10: PZ254V-11-02P; HDRV2W64P0X254_1X2_508X250X873P; Manufacturer_Part_Number PZ254V-11-02P; LCSC C492401
J11: ICH-340-CTT; DIPS762W74P254L5080H338Q40N; Manufacturer_Part_Number ICH-340-CTT; LCSC C84681
LED1, LED2: 19-217_GHC-YR1S2_3T; LEDC1608X50N; Manufacturer_Part_Number 19-217/GHC-YR1S2/3T; Mouser Part Number 638-19217GHCYR1S23T
Q1: AO3401A; SOT95P280X125-3N; Manufacturer_Part_Number AO3401A; LCSC C15127
R1: 0603WAF1201T5E; RESC1608X55N; Manufacturer_Part_Number 0603WAF1201T5E; LCSC C22765
R2, R14: RC0603FR-071KL; RESC1608X55N; Manufacturer_Part_Number RC0603FR-071KL; Mouser Part Number 603-RC0603FR-071KL
R3: 10k; RESC1608X55N; JLCPCB Part Number C25804
U1: HT75xx-1-SOT89; SOT-89-3

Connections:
5V USB: C1.2, C2.2, C4.1, C5.2, D2.2, IC4.4 (VCC), IC4.8 (CE), J5.1 (VBUS), J8.2, J11.16, LED1.2, LED2.2, Q1.1, R3.1; also elsewhere on the board
+3v3: C8.2, U1.3 (VOUT); also elsewhere on the board
/Power/D+: J5.3 (D+), J11.5
/Power/D-: J5.2 (D-), J11.6
/Power/PA9: J6.2
/Power/PA10: J7.1
/Power/RXD: J7.2, J11.3
/Power/TXD: J6.1, J11.2
BAT volt: C6.2, IC4.5 (BAT), J10.1, Q1.2; also elsewhere on the board
GND: C1.1, C2.1, C3.2, C4.2, C5.1, C6.1, C7.1, C8.1, IC4.1 (TEMP), IC4.3 (GND), J5.4 (ID), J5.5 (GND), J10.2, J11.1, R1.1, R3.2, U1.1 (GND); also elsewhere on the board
LDO: C7.2, J8.1, U1.2 (VIN); also elsewhere on the board
unnamed: C3.1, J11.4
unnamed: D1.1, D2.1, J8.3
unnamed: D1.2, Q1.3
unnamed: IC4.2 (PROG), R1.2
unnamed: IC4.6 (~STDBY), R14.2
unnamed: IC4.7 (~CHRG), R2.2
unnamed: LED1.1, R2.1
unnamed: LED2.1, R14.1

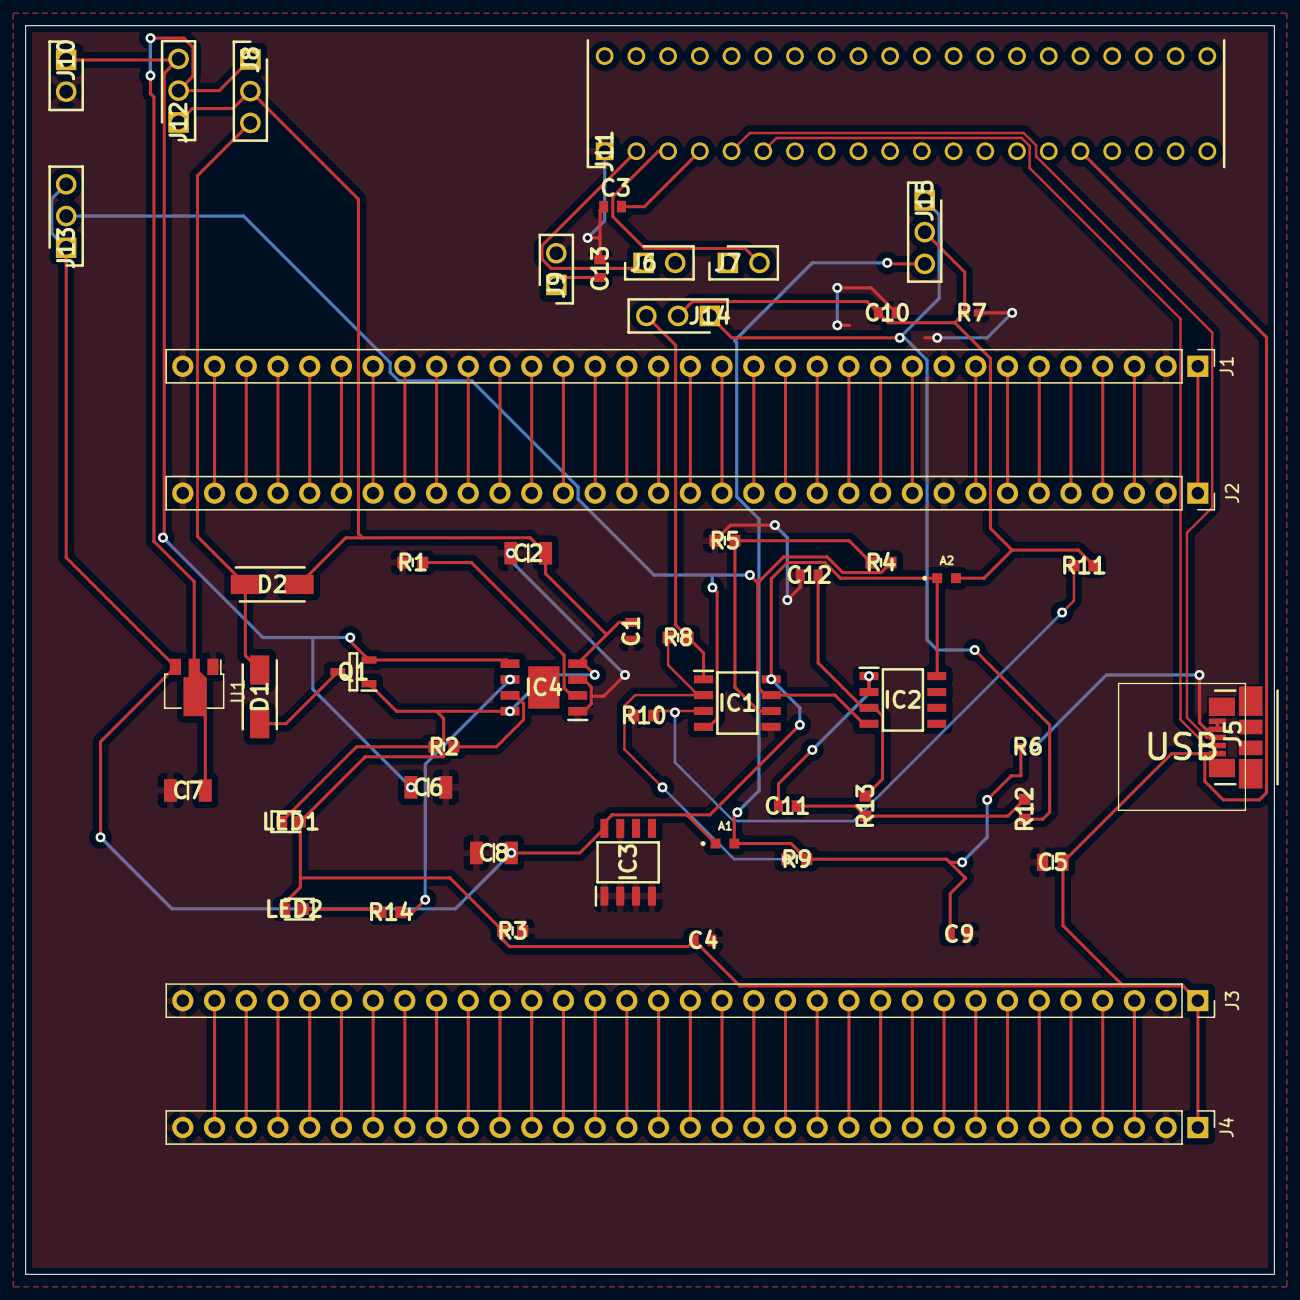
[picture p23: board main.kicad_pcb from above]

Board: 2 copper layers, 100.0 x 100.0 mm, 54 parts (0 on the bottom side), 89 nets.

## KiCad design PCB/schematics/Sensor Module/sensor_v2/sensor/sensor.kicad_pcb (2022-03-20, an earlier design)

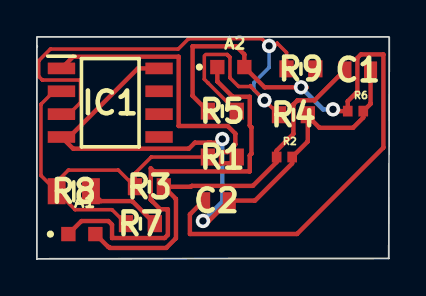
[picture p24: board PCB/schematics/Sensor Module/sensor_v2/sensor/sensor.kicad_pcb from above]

Board: 2 copper layers, 19.6 x 12.3 mm, 14 parts (0 on the bottom side), 8 nets.

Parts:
A1, A2: ALS-PT19-315C/L177/TR8; XDCR_ALS-PT19-315C_L177_TR8
C1, C2: CL10A105KB8NNNC; CAPC1608X90N
IC1: LM358DT; SOIC127P600X175-8N
R1, R3, R4, R5, R7: RC0603FR-071KL; RESC1608X55N
R2, R6: AC0402FR-07536KL; RESC1005X37N
R8: CR0805-FX-5110ELF; RESC2012X60N
R9: RC0603JR-0710KL; RESC1608X55N

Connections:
3v3: A1.1, A2.1
+3v3: C1.2, C2.2, IC1.4 (VCC-), IC1.8 (VCC+), R2.2, R4.2, R6.2
+5v: R7.2, R8.2
IN1+: IC1.3 (IN1+), R4.1, R5.1, R9.1
IN1-: IC1.2 (IN1-), R1.1, R3.1, R7.1, R8.1
Vdiff: IC1.1 (OUT1), R1.2
Vout1: A1.2, C1.1, R2.1, R3.2
Vout2: A2.2, C2.1, R5.2, R6.1

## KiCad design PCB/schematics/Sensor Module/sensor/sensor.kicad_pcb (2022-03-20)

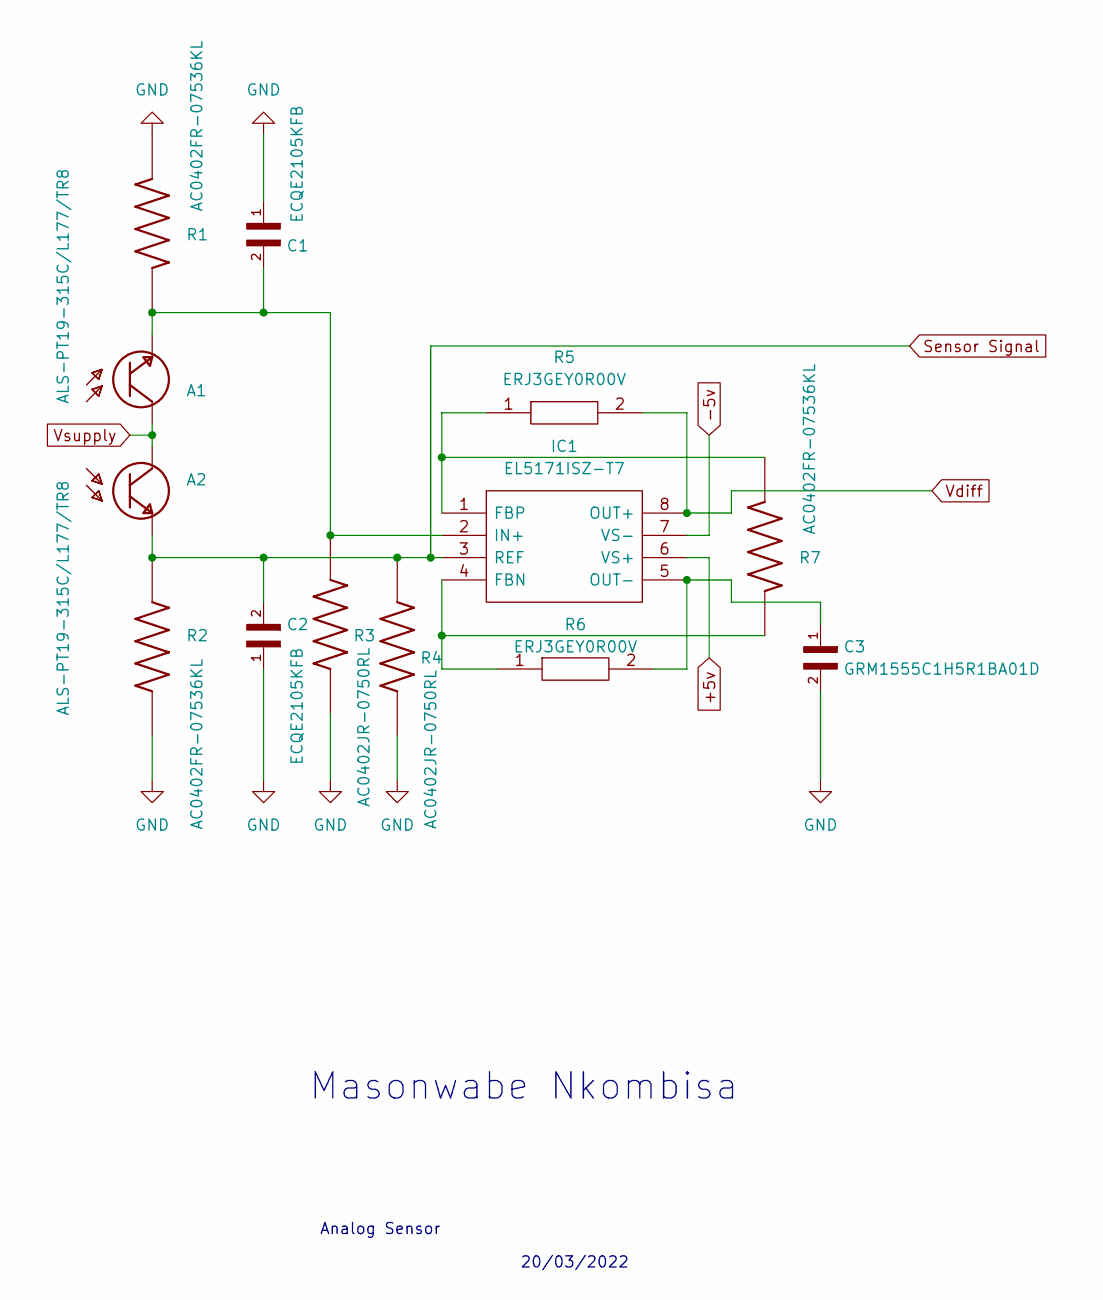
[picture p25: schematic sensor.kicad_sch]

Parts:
A1, A2: ALS-PT19-315C/L177/TR8; XDCR_ALS-PT19-315C_L177_TR8; PARTREV 5; LCSC C146233
C1, C2: ECQE2105KFB; CAPRR1000W80L1850T740H2000; PARTREV 11-Oct-17; LCSC C178438
C3: GRM1555C1H5R1BA01D; CAPC1005X55N; LCSC C415534
IC1: EL5171ISZ-T7; SOIC127P600X175-8N; Manufacturer_Part_Number EL5171ISZ-T7; Mouser Part Number 968-EL5171ISZ-T7
R1, R2, R7: AC0402FR-07536KL; RESC1005X37N; LCSC C144748
R3, R4: AC0402JR-0750RL; RESC1005X37N; LCSC C227387
R5, R6: ERJ3GEY0R00V; ERJ3EKF1000V; Manufacturer_Part_Number ERJ3GEY0R00V; LCSC C122704

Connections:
+5v: IC1.6 (VS+)
-5v: IC1.7 (VS-)
GND: C1.1, C2.1, C3.2, R1.1, R2.1, R3.1, R4.1
unnamed: A1.2, C1.2, IC1.2 (IN+), R1.2, R3.2
unnamed: C3.1, IC1.5 (OUT-), R6.2
unnamed: IC1.1 (FBP), R5.1, R7.1
unnamed: IC1.4 (FBN), R6.1, R7.2
Sensor Signal: A2.2, C2.2, IC1.3 (REF), R2.2, R4.2
Vdiff: IC1.8 (OUT+), R5.2
Vsupply: A1.1, A2.1

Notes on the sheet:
20/03/2022
Masonwabe Nkombisa
Analog Sensor

Board: 2 copper layers, 13 parts (0 on the bottom side), 8 nets, no tracks yet.

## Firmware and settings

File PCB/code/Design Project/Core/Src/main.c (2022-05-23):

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
/* Includes ------------------------------------------------------------------*/
#include "main.h"

/* USER CODE BEGIN Includes */
#include "string.h"
/* USER CODE END Includes */

 I2C_HandleTypeDef hi2c1;

UART_HandleTypeDef huart1;

void SystemClock_Config(void);
static void MX_GPIO_Init(void);
static void MX_I2C1_Init(void);
static void MX_USART1_UART_Init(void);
/* USER CODE BEGIN 0 */
//General purpose Function to send a char array over the UART and to automatically send a new line character after it
void debugPrintln(UART_HandleTypeDef *uart_handle,
char _out[]){
	HAL_UART_Transmit(uart_handle, (uint8_t *) _out,
strlen(_out), 60);
	char newline[2] = "\r\n";
	HAL_UART_Transmit(uart_handle, (uint8_t *)
newline, 2, 10);
}
/* USER CODE END 0 */

/**
  * @brief  The application entry point.
  * @retval int
  */
int main(void)
{
  /* MCU Configuration--------------------------------------------------------*/

  /* Reset of all peripherals, Initializes the Flash interface and the Systick. */
  HAL_Init();

  /* Configure the system clock */
  SystemClock_Config();

  /* Initialize all configured peripherals */
  MX_GPIO_Init();
  MX_I2C1_Init();
  MX_USART1_UART_Init();
  /* Infinite loop */
  /* USER CODE BEGIN WHILE */
  while (1)
  {
    /* USER CODE END WHILE */
	   //Demo sending data over UART2 to Laptop
	   debugPrintln(&huart1, "Hello, this is STMF0 Discovery board"); // print full line
	   //Flash Blue LED
	   HAL_GPIO_TogglePin(GPIOC, GPIO_PIN_8);
	   HAL_Delay(1000);
    /* USER CODE BEGIN 3 */
  }
  /* USER CODE END 3 */
}

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


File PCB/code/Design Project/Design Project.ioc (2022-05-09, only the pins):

Mcu.UserName=STM32F051R8Tx
PA1.Signal=GPIO_Analog
PA10.Signal=USART1_RX
PA9.Signal=USART1_TX
PB7.Signal=I2C1_SDA
PB8.Signal=I2C1_SCL
PC14-OSC32_IN.Signal=GPIO_Analog
PC8.Signal=GPIO_Output

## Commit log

2022-03-10 1st commit
    [example1_libraries.kicad_pcb, example1_libraries.kicad_sch, main.kicad_pcb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]
2022-03-10 Microcontroller Bill Of Material Version 1
    [BOM_Microcontroller.xlsx]
2022-03-10 Power_submodele_BOM v1
    [Power_submodule_BOM.xlsx]
2022-03-10 power schematic v1
    [power_submodule.sch]
2022-03-11 Microcontroller Submodule Version 1
    [Microcontroller Submodule.kicad_sch]
2022-03-12 Analog sensor BOM
    [BOMAnalogSensor.xlsx]
2022-03-12 microcontroller interfacing submodule version 2
    [Microcontroller_Submodule_BOM.xlsx]
2022-03-12 removed the old bill of material
    [BOM_Microcontroller.xlsx]
2022-03-12 updated microcontroller schematic
    [Microcontroller Submodule.kicad_sch]
2022-03-12 power submodule BOM version2
    [power_submodule_BOM_v2.xlsx]
2022-03-12 4TH WEEK, CHANGES FOR SENSING
    [BOM -Sensor.xlsx, main.kicad_sch, sensing.kicad_sch]
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2022-03-12 added FTDIto the schematic
    [power_submodule_v2.sch]
2022-03-20 updated bill of material Microcontroller
    [Microcontroller_Submodule_BOM.xlsx]
2022-03-20 updated power schematic
    [power.kicad_sch]
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2022-03-20 updated power BOM
    [POWER_MODULE_v3.xlsx]
2022-03-20 moved power schematics to main
    [power_submodule.sch, power_submodule_v2.sch]
2022-03-20 updated microcontroller bill of material
    [Microcontroller_Submodule_BOM.xlsx]
2022-03-20 Week 5 submission, with improved version of the sensor
    [AC0402FR-07536KL.stl, AC0402FR-07536KL.stp, AC0402JR-0750RL.stl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]
2022-03-20 Week 5 submission, with analog sensor.
    [sensor.kicad_sch]
2022-03-20 updated bill of material
    [Microcontroller_Submodule_BOM.xlsx]
2022-03-20 Week 5 submission, with analog sensor with pcb updated
    [sensor.kicad_pcb, sensor.kicad_sch]
2022-03-20 updated microcontroller footprints and that..
    [AT24C256C-SSHL-T.stl, AT24C256C-SSHL-T.stp, CL10A335KP8NNNC.stl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]
2022-03-21 assigned new footprints
    [power.kicad_sch]
2022-03-21 added power library
    [0603WAF1002T5E.stl, 0603WAF1002T5E.stp, 0603WAF470JT5E.stl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]
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2022-03-21 Sensing module combined with main module
    [sensing.kicad_sch, sensor.kicad_sch]
2022-03-21 power and microcontroller updated
    [microcontroller_interfacing.kicad_sch, power.kicad_sch]
2022-03-21 changes made to all
    [main.kicad_sch, microcontroller_interfacing.kicad_sch, power.kicad_sch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]
2022-03-21 microcontroller files
    [CL10A475KA8NQNC.stl, CL10A475KA8NQNC.stp, CL10A475KO8NNNC.stl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]
2022-03-21 sensor bill of material
    [BOMAnalogSensor_wk5.xlsx]
2022-03-21 power module
    [power_submodule_v2.kicad_sch]
2022-03-21 changed USB MICRO
    [POWER_MODULE_v3.xlsx, main.kicad_sch, power.kicad_sch]
2022-03-21 modified power library
    [47346-0001.stp]
2022-03-21 updated stuff
    [0603WAF1002T5E.stl, 0603WAF1002T5E.stp, 0603WAF470JT5E.stl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]
2022-03-21 git main schematics updated
    [main.kicad_pcb, main.kicad_sch, microcontroller_interfacing.kicad_sch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]
2022-03-21 changed made on PCD
    [main.kicad_pcb, main.kicad_sch, power.kicad_sch]
2022-03-21 PCB geber files
    [main-B_Cu.gbr, main-B_Mask.gbr, main-B_Paste.gbr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]
2022-03-22 wired the pcb a bit
    [main.kicad_pcb]
2022-03-22 main with 0 DRC errors
    [main.kicad_pcb]
2022-03-22 Update on pcb
    [main.kicad_pcb]
2022-03-23 pcb with no errors, violations
    [main-B_Cu.gbr, main-B_Mask.gbr, main-B_Paste.gbr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]
2022-04-04 main modified by masonwabe
    [main.kicad_pcb]
2022-04-04 updated PCB with mount holes
    [main.kicad_pcb]
2022-04-05 latest changes
    [main.kicad_sch, microcontroller_interfacing.kicad_sch, power.kicad_sch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]
2022-04-05 updated power BOM and total cost
    [POWER_MODULE_v3.xlsx]
2022-04-06 Modified pcb to reduced the gnd and 3.3v lines
    [main.kicad_pcb, main.kicad_sch, power.kicad_sch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]
2022-04-08 added test points and jumpers
    [main.kicad_sch, microcontroller_interfacing.kicad_sch, power.kicad_sch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]
2022-04-08 added more test points
    [main.kicad_pcb, main.kicad_sch, sensing.kicad_sch]
2022-04-08 pcb update
    [main.kicad_pcb]
2022-04-08 gerber files and dat
    [main-B_Cu.gbr, main-B_Mask.gbr, main-B_Paste.gbr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]
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2022-04-11 Added position files
    [main-bottom-pos.csv, main-top-pos.csv]
2022-04-11 gerber files final
    [main-B_Cu.gbl, main-B_Mask.gbs, main-B_Paste.gbp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]
2022-04-12 created BOM
    [BOMAnalogSensor_wk5.xlsx, main.kicad_sch, microcontroller_interfacing.kicad_sch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]
2022-04-16 modified power schematic
    [main.kicad_pcb, main.kicad_sch, microcontroller_interfacing.kicad_sch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]
2022-04-16 new PCB
    [main.kicad_pcb, main.kicad_sch, microcontroller_interfacing.kicad_sch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]
2022-04-16 new footprints
    [47346-0001.stp]
2022-04-16 generated Gerbers
    [main-B_Cu.gbl, main-B_Mask.gbs, main-B_Paste.gbp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]
2022-04-16 removed old files
    [main-B_Cu.gbl, main-B_Mask.gbs, main-B_Paste.gbp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]
2022-04-17 changed power schematic
    [main.kicad_pcb, main.kicad_sch, main.xlsx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]
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2022-04-22 Added sensor sch to the schematics folder
    [sensing.kicad_sch]
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2022-04-25 created new BOM,POS and Gerbers
    [main-CuBottom.gbr, main-CuTop.gbr, main-EdgeCuts.gbr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]
2022-05-23 checking if readmefile updated
    [main.kicad_pcb]

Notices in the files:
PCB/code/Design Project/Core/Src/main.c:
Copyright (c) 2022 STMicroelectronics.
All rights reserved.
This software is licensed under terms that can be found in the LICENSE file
